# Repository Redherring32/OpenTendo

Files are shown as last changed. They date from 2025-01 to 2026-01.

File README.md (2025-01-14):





<br />

<p align="center">
  OSHW logo
</p>

# Open 'Tendo
An Open-Source HardWare (OSHW) recreation of the original 1985 Front-Loading NES motherboard.

## Note on RGB and HDMI

Neither RGB nor HDMI video output were or are a goal of the OpenTendo project, the goal was/is documentation and preservation, and the project was an exercise in reverse engineering. As such "improved" video outputs will not be added to OpenTendo.

NESRGB and Hi-Def NES can be installed as normal, but will not be incorporated into the OpenTendo PCB

## Repository Structure
### Branches
| Branch | Description |
| --- | --- |
| master | Latest revision of OpenTendo. This is a almost 1:1 of the OEM NES. |
| modded | Modded version of the latest revision (`master`). This houses any modification that is not in the OEM NES. |
| vX.X | Previous revisions of OpenTendo. (*ex.* v1.3) |
| vX.X_modded | Modded version of a previous revision. (*ex.* v1.3_modded) |

### File Structure
```
.
├── BOM              # Contains the bill of materials.
├── Board Files      # Contains all files necessary to open the project in KiCad.
|   └── Libraries    # Contains a library of all of the custom footprints used on the board.
├── Scans            # Contains the scans of the OEM NES board.
└── Schematics       # Contains schematics for the OEM frontloading NES board revisions,
                       some schematics represent more than one revision
```

The gerber files required to order PCBs can be found under [releases](https://github.com/Redherring32/OpenTendo/releases).

## Recommended PCB specs
* 2 layers

* 119mmx196mm

* 1.6mm thickness

* HASL or ENiG surface finish

* And any color you want!

> [!IMPORTANT]
> OpenTendo have some solder mask overlapping the edge connector to secure the pads and the thin traces. Some fabricators might see this as an error and might try to fix it.
>
> We recommend leaving a note saying that the solder mask overlap on the edge connector is intentional and NOT an error when ordering the PCB.

Board Front

The design is as true to the original board as possible, with subtle changes where needed to compensate for outdated/unsourcable parts,
as well as some improvements. (Expansion audio enabled, and other minor changes)

Since this project is open-source you may do as you like with it, whether that is to make boards for personal use, sell replacement NES boards, or to use the provided info for further custom PCB work/designs.

I am not in any way affiliated with Nintendo, I'm just doing this in my free time as a stepping stone into further Reverse Engineering work.

>[!NOTE]
> Please check the [BOM](./BOM#from-the-oem-nes) for the list of components needed from the OEM NES

## License

Licensed under
the TAPR Open Hardware License (www.tapr.org/OHL)

©Redherring32 2019-2024

## Credits
*=Lockster=* - Helping me tremendously along the way, keeping me from going insane, and cleaning up/helping with the final schematic. 

*Krzysiobal* - Putting together the NES-CPU-11 schematic that my schematic is largely referrenced against.

*[Muramasa](https://www.muramasaentertainment.com/)* - Ported to KiCad v8, PCB clean up, and fixing the EXP port footprint.

*[Kamoteshake](https://github.com/kamoteshake)* - Schematic clean up and fixing the EXP port footprint.

And to all of the awesome people in the NES scene, I wouldn't have been able to do this without the awesome work that some very clever people did before I got here.

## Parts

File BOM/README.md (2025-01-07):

# Bill of Materials
This is a list of components you need to build the OpenTendo NES. You will need some components from the original NES and have to order more modern components. Open [interactive_bom.html](./interactive_bom.html) on a browser to open an interactive BOM which shows you where the component is located on the board.

## From the OEM NES
| Reference | Qty | Part | Description |
| --- | :-: | ---- | --- |
| U5 | 1 | **NTSC:** RP2C02<br />**PAL:** RP2C07 | PPU |
| U6 | 1 | **NTSC:** RP2A03<br/>**PAL:** RP2A07 | CPU |
| U10 | 1 | 3193A | CIC |
| Q1 | 1 | A937 | Epitaxial planar PNP transistor |
| Q2, Q3| 2 | C2021 | 3 pin small signal bipolar transistor |
| DA1, DA3 | 2 | DAN601 | 7 pin small signal diode array |
| DA2, DA4 | 2 | UPA64H | 7 pin high speed switching diode array |
| P2 | 1 | Connector | 48 pin expansion port |
| P6 | 1 | Connector | 5 pin connector for the power/reset breakout board |

### Alternatives
| Reference | Qty | Part | Description |
| --- | :-: | ---- | --- |
| U5 | 1 | **NTSC:** UA6528 <sup>[1]</sup><br />**PAL:** UA6528P | PPU clone |
| U6 | 1 | **NTSC:** UA6527 <sup>[2]</sup><br />**PAL:** UA6527P | CPU clone |
| U10| 1 | [NullCIC](https://github.com/Redherring32/NullCIC)<sup>[3]</sup> | Small board to replace CIC |
| Q1 | 1 | [2SA937](https://octopart.com/2sa937-rohm-2179925)<sup>[4]</sup> | Epitaxial planar PNP transistor |
| Q2, Q3 | 2 | [2SC2021](https://octopart.com/2sc2021-rohm-2177186)<sup>[5]</sup> | 3 pin small signal bipolar transistor |
| DA1, DA3 | 2 | [DAN601](https://octopart.com/dan601-rohm-14372173)<sup>[6]</sup> | 7 pin small signal diode array |
| P2 | 2 | [PPPC241LFBN-RC](https://octopart.com/pppc241lfbn-rc-sullins-271073)<sup>[7]</sup> | 24 Pins Header Connector 0.100" (2.54mm) Through Hole |

> [!NOTE]
> <sup>[1]</sup> While it works as a direct drop-in replacement, it isn't known whether it is compatible with all NES games.
>
> <sup>[2]</sup> They are known to have different sounding audio due to swapped duty cycles, as such they aren't a 100% identical substitute, they otherwise work though.
>
> <sup>[3]</sup> [NullCIC](https://github.com/Redherring32/NullCIC) is optional. Use this if you want to remove the CIC but still have the reset functionality.
>
> <sup>[4][5][6]</sup> These components are discontinued and difficult to find. If you could find them, we recommend replacing the OEM. If not, the OEM components should still be fine.
>
> <sup>[7]</sup> If you don't want to use the OEM expansion port, you can replace it with a header pin connector or not put anything at all. OpenTendo should still work without the expansion port. 

## What to buy
We recommend using Octopart's [BOM tool](https://octopart.com/bom-tool/) and import the [BOM.csv](BOM.csv). This tool makes ordering from multiple Octopart's authorized distributors (Digikey, Mouser, etc.) easier. 

### Resistors
| Reference | Qty | Part | Description |
| --- | :-: | ---- | --- |
| RA1 | 1 | [4613X-101-103LF](https://octopart.com/4613x-101-103lf-bourns-1656444) | 10k Ohm ±2% 200mW Bussed 12 Resistor Array 13-SIP |
| RA2 | 1 | [4605X-101-682LF](https://octopart.com/4605x-101-682lf-bourns-1624703) | 6.8k Ohm Bussed 4 Resistor Array 5-SIP |
| R1 | 1 | [RNF14FTD1M00](https://octopart.com/rnf14ftd1m00-stackpole+electronics-19224733) | 1M OHM 1% 1/4W |
| R2, R12 | 2 | [CF18JT510R](https://octopart.com/cf18jt510r-stackpole+electronics-19205768) | 510 OHM 5% 1/8W |
| R3, R4 | 2 | [CF18JT100R](https://octopart.com/cf18jt100r-stackpole+electronics-19205641) | 100 OHM 5% 1/8W |
| R5 | 1 | [CF18JT220R](https://octopart.com/cf18jt220r-stackpole+electronics-19205701) | 220 OHM 5% 1/8W |
| R6 | 1 | [CF18JT47K0](https://octopart.com/cf18jt47k0-stackpole+electronics-19205759) | 47K OHM 5% 1/8W |
| R7, R9 | 2 | [CF18JT20K0](https://octopart.com/cf18jt20k0-stackpole+electronics-19205697) |	20K OHM 5% 1/8W |
| R8 | 1 | [CF18JT12K0](https://octopart.com/cf18jt12k0-stackpole+electronics-19205652) |	12K OHM 5% 1/8W |
| R10 | 1 | [CF18JT220K](https://octopart.com/cf18jt220k-stackpole+electronics-19205700) | 220K OHM 5% 1/8W |
| R11 | 1 | [CF18JT1K20](https://octopart.com/cf18jt1k20-stackpole+electronics-19205676) | 1.2K OHM 5% 1/8W |
| R13 | 1 | [CFR-25JB-52-150K](https://octopart.com/cfr-25jb-52-150k-yageo-22569037) | 150K OHM 5% 1/4W |
| R17 | 1 | [CF14JT2K20](https://octopart.com/cf14jt2k20-stackpole+electronics-19205454) | 2.2K OHM 5% 1/4W |
| R18, R19 | 2 | [CF18JT1K00](https://octopart.com/cf18jt1k00-stackpole+electronics-19205674) | 1K OHM 5% 1/8W |

### Capacitors
| Reference | Qty | Part | Description |
| --- | :-: | ---- | --- |
| BC1, BC2 | 2 | [K153K10X7RF5UH5](https://octopart.com/k153k10x7rf5uh5-vishay-44033224) | 0.015 µF 50V Ceramic Capacitor |
| TC1 | 1 | [GKG30015](https://octopart.com/gkg30015-panasonic-120079986)<sup>[1]</sup> | 6.5-30 pF Capacitor Trimmer |
| C1 | 1 | [ECE-A0JKA101I](https://octopart.com/ece-a0jka101i-panasonic-15327038) | 100 µF 6.3 V Electrolytic Capacitor |
| C2, C3, C4, C10,<br />C11, C12, C13,<br />C14, C15, C16,<br />C17, C18, C19,<br />C22, C24, C26,<br />C32, C38, C39,<br />C40 | 20 | [K103K10X7RF5UH5](https://octopart.com/k103k10x7rf5uh5-vishay-44280222) | 10000 pF 50V Ceramic Capacitor |
| C5, C27, C28, C29,<br />C30, C31, C33,<br />C34, C35, C36,<br />C37 | 11 | [K331K15X7RF53L2](https://octopart.com/k331k15x7rf53l2-vishay-42623274) | 330 pF 50V Ceramic Capacitor |
| C8, C46 | 2 | [K104K15X7RF5UH5](https://octopart.com/k104k15x7rf5uh5-vishay-40993312) | 0.1 µF 50V Ceramic Capacitor |
| C9 | 1 | [ECA-1HHG2R2I](https://octopart.com/eca-1hhg2r2i-panasonic-12553061) | 2.2 µF 50 V Electrolytic Capacitor |
| C20, C21, C44 | 3 | [K221K15X7RF5TL2](https://octopart.com/k221k15x7rf5tl2-vishay-39474895) | 220 pF 50V Ceramic Capacitor 2.5mm |
| C23 | 1 | [UVR2A010MDD1TD](https://octopart.com/uvr2a010mdd1td-nichicon-10319218) | 1 µF 100 V Electrolytic Capacitor |
| C41 | 1 | [FG18C0G1H180JNT00](https://octopart.com/fg18c0g1h180jnt00-tdk-75262881) | 18 pF 50V Ceramic Capacitor |
| C42 | 1 | [K150J15C0GF5TL2](https://octopart.com/k150j15c0gf5tl2-vishay-39474466) | 15 pF 50V Ceramic Capacitor |
| C43, C45 | 2 | [K560J15C0GF5TL2](https://octopart.com/k560j15c0gf5tl2-vishay-39474510)<sup>[2]</sup> | 56 pF 50V Ceramic Capacitor |

> [!NOTE]
> <sup>[1]</sup> You might have to trim the capacitor to get a stable clock (21.47727MHz for NTSC and 26.601712MHz for PAL). If you don't have a way to probe the clock, We recommend just using the X1 and TC1 from the OEM NES.
>
> <sup>[2]</sup> The OEM is using 51pF for C43 and C45. It's been difficult to find a 51pF Ceramic Capacitor. Using a 56pF is fine and have been tested.

### ICs
| Reference | Qty | Part | Description |
| --- | :-: | ---- | --- |
| U1, U4 | 2 | [6116SA15SOG](https://octopart.com/6116sa15sog-renesas-106910578)<sup>[1]</sups> | SRAM Chip Async Single 5V 16K-Bit 2K x 8 15ns 24-Pin SOIC |
| U2 | 1 | [SN74HC373N](https://octopart.com/sn74hc373n-texas+instruments-471147) | D-Type Transparent Latch 1 Channel 8:8 IC Tri-State 20-PDIP |
| U3 | 1 | [SN74HC139N](https://octopart.com/sn74hc139n-texas+instruments-17212) | Decoder/Demultiplexer 1 x 2:4 16-PDIP |
| U7, U8 | 2 | [SN74HC368N](https://octopart.com/sn74hc368n-texas+instruments-51845) | Buffer, Inverting 2 Element 2, 4 (Hex) Bit per Element 3-State Output 16-PDIP |
| U9 | 1 | [SN74HCU04N](https://octopart.com/sn74hcu04n-texas+instruments-465549) | Inverter IC 6 Channel 14-PDIP |

#### Alternatives
| Reference | Qty | Part | Description |
| --- | :-: | ---- | --- |
| U1, U4 | 2 | [6116SA15TPG](https://octopart.com/6116sa15tpg-renesas-106910580) | SRAM - Asynchronous Memory IC 16Kb (2K x 8) Parallel 15ns 24-PDIP |

> [!NOTE]
> <sup>[1]</sup> This component is an SOIC. You would need an SOIC to DIP adaptor (`PA0009`), listed in [Others](#others), to be able to use this component. If you're not comfortable working with SOIC, We recommend looking for the alternative `6116SA15TPG` or use the SRAM from the OEM NES.

### Connectors
| Reference | Qty | Part | Description |
| --- | :-: | ---- | --- |
| U5, U6 | 2 | [ED40DT](https://octopart.com/ed40dt-on+shore+technology-5349672) | 40 (2 x 20) Pos DIP, 0.6" (15.24mm) Row Spacing Socket Tin Through Hole |
| P4, P5 | 2 | [S7B-PH-K-S(LF)(SN)](https://octopart.com/s7b-ph-k-s%28lf%29%28sn%29-jst-248888) | JST PH 2mm 7 Pins Male |

### Others
| Reference | Qty | Part | Description |
| --- | :-: | ---- | --- |
| X1 | 1 | **NTSC**: [ECS-214-S-4X](https://octopart.com/ecs-214-s-4x-ecs+international-88334749)<br />**PAL:** N/A<sup>[1]</sup>  | **NTSC:** 21.47727MHz Crystal<br />**PAL:** 26.601712MHz Crystal |
| X2 | 1 | [CSTLS4M00G56-B0](https://octopart.com/cstls4m00g56-b0-murata-10326657) | 4 MHz Ceramic Resonator Built in Capacitor 47 pF |
| D1, D2 | 2 | [1N5231BTR](https://octopart.com/1n5231btr-onsemi-12156453) | Zener Diode 5.1 V 500 mW Through Hole |
| FC1 | 1 | [B78108S1393K](https://octopart.com/b78108s1393k-epcos-39569030) | 39 µH Unshielded Drum Core, Wirewound Inductor 470 mA 1.02Ohm Max Axial |
| FC2 | 1 | [28L0138-10R-10](https://octopart.com/28l0138-10r-10-laird-19252911) | 75 Ohms @ 100 MHz 1 Ferrite Bead Axial 5A 10mOhm |
| U1, U4 | 2 | [PA0009](https://octopart.com/pa0009-chip+quik-51024752)<sup>[2]</sup> | SOIC-24 to DIP-24 SMT Adapte |

> [!NOTE]
> <sup>[1]</sup> We couldn't find a good part number for a crystal for PAL system. We recommend searching the internet to find a 26.601712MHz crystal for PAL.
>
> <sup>[2]</sup> You only need this adaptor if you're using the `6116SA15SOG` SRAM. When using this adaptor, you will need additional header connector (`PPPC241LFBN-RC`).

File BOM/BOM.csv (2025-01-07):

Query | Qty | Manufacturer | MPN | Octopart URL | Part Description | Description | Schematic Reference | Internal Part Number | Lifecycle | Lead Time | RoHS | Total Qty (@ Batch Size: 1) | SKU | SKU | SKU | SKU | SKU | Packaging | Packaging | Packaging | Packaging | Packaging | Unit Price (@ Batch Size: 1) | Unit Price (@ Batch Size: 1) | Unit Price (@ Batch Size: 1) | Unit Price (@ Batch Size: 1) | Unit Price (@ Batch Size: 1) | In Stock | In Stock | In Stock | In Stock | In Stock | MOQ | MOQ | MOQ | MOQ | MOQ | URL | URL | URL | URL | URL | Distributor [Lowest Price (Preferred Distributors)] | SKU [Lowest Price (Preferred Distributors)] | Packaging [Lowest Price (Preferred Distributors)] | Unit Price (@ Batch Size: 1) [Lowest Price (Preferred Distributors)] | Line Total [Lowest Price (Preferred Distributors)] | Batch Total [Lowest Price (Preferred Distributors)] | In Stock [Lowest Price (Preferred Distributors)] | MOQ [Lowest Price (Preferred Distributors)] | URL [Lowest Price (Preferred Distributors)] | Notes
 |  |  |  |  |  |  |  |  |  |  |  |  | Digi-Key | Mouser | Newark | Onlinecomponents.com | RS Components | Digi-Key | Mouser | Newark | Onlinecomponents.com | RS Components | Digi-Key | Mouser | Newark | Onlinecomponents.com | RS Components | Digi-Key | Mouser | Newark | Onlinecomponents.com | RS Components | Digi-Key | Mouser | Newark | Onlinecomponents.com | RS Components | Digi-Key | Mouser | Newark | Onlinecomponents.com | RS Components
CSTLS4M00G56-B0 | 1 | Murata | CSTLS4M00G56-B0 | https://octopart.com/cstls4m00g56-b0-murata-10326657 | Ceramic Resonator 4MHz ±0.5% (Tol) -0.4/0.2% (Stability) 47pF 30Ohm 3-Pin Thru-Hole Bulk |  | X2 |  | NRND (Last Updated: 2 weeks ago) | 15w | Compliant | 1 | 490-7036-ND | 81-CSTLS4M00G56-B0 | 70AC3726 |  |  | Bulk | Bulk |  |  |  | 0.21 | 0.21 | 0.209 |  |  | 4715 | 2001 | 324 |  |  | 1 | 1 | 1 |  |  | https://octopart.com/opatz8j6/a1 | https://octopart.com/opatz8j6/a1 | https://octopart.com/opatz8j6/a1 |  |  | Newark | 70AC3726 |  | 0.209 | 0.209 | 0.209 | 324 | 1 | https://octopart.com/opatz8j6/a1
ECS-214-S-4X | 1 | ECS International | ECS-214-S-4X | https://octopart.com/ecs-214-s-4x-ecs+international-88334749 |  |  | X1 |  |  |  | Compliant | 1 |  | 520-HCU2147-SX |  |  |  |  | Bulk |  |  |  |  | 0.69 |  |  |  |  | 558 |  |  |  |  | 1 |  |  |  |  | https://octopart.com/opatz8j6/a1 |  |  |  | Mouser | 520-HCU2147-SX | Bulk | 0.69 | 0.69 | 0.69 | 558 | 1 | https://octopart.com/opatz8j6/a1
SN74HCU04N | 1 | Texas Instruments | SN74HCU04N | https://octopart.com/sn74hcu04n-texas+instruments-465549 | Gate / Inverter Logic IC Leaded Process; function (IC): Hex Inverter; Base Number: 7404 |  | U9 |  | Production (Last Updated: 1 week ago) | 1w | Compliant | 1 | 296-9820-5-ND | 595-SN74HCU04N |  |  |  | Tube | Tube |  |  |  | 0.63 | 0.59 |  |  |  | 2448 | 1088 |  |  |  | 1 | 1 |  |  |  | https://octopart.com/opatz8j6/a1 | https://octopart.com/opatz8j6/a1 |  |  |  | Mouser | 595-SN74HCU04N | Tube | 0.59 | 0.59 | 0.59 | 1088 | 1 | https://octopart.com/opatz8j6/a1
SN74HC368N | 1 | Texas Instruments | SN74HC368N | https://octopart.com/sn74hc368n-texas+instruments-51845 | Buffer/Line Driver 6-CH Inverting 3-ST CMOS 16-Pin PDIP Tube |  | U8 |  | Production (Last Updated: 1 week ago) | 1w | Compliant | 1 | 296-8308-5-ND | 595-SN74HC368N |  |  |  | Tube | Tube |  |  |  | 0.65 | 0.57 |  |  |  | 4259 | 951 |  |  |  | 1 | 1 |  |  |  | https://octopart.com/opatz8j6/a1 | https://octopart.com/opatz8j6/a1 |  |  |  | Mouser | 595-SN74HC368N | Tube | 0.57 | 0.57 | 0.57 | 951 | 1 | https://octopart.com/opatz8j6/a1
SN74HC368N | 1 | Texas Instruments | SN74HC368N | https://octopart.com/sn74hc368n-texas+instruments-51845 | Buffer/Line Driver 6-CH Inverting 3-ST CMOS 16-Pin PDIP Tube |  | U7 |  | Production (Last Updated: 1 week ago) | 1w | Compliant | 1 | 296-8308-5-ND | 595-SN74HC368N |  |  |  | Tube | Tube |  |  |  | 0.65 | 0.57 |  |  |  | 4259 | 951 |  |  |  | 1 | 1 |  |  |  | https://octopart.com/opatz8j6/a1 | https://octopart.com/opatz8j6/a1 |  |  |  | Mouser | 595-SN74HC368N | Tube | 0.57 | 0.57 | 0.57 | 951 | 1 | https://octopart.com/opatz8j6/a1
ED40DT | 2 | On Shore Technology | ED40DT | https://octopart.com/ed40dt-on+shore+technology-5349672 | Conn DIP Socket SKT 40 POS Solder ST Thru-Hole |  | U5, U6 |  |  | 8w | Compliant | 2 | ED3048-5-ND |  |  |  |  | Tube |  |  |  |  | 0.59 |  |  |  |  | 1677 |  |  |  |  | 1 |  |  |  |  | https://octopart.com/opatz8j6/a1 |  |  |  |  | DigiKey | ED3048-5-ND | Tube | 0.59 | 1.18 | 1.18 | 1677 | 1 | https://octopart.com/opatz8j6/a1
SN74HC139N | 1 | Texas Instruments | SN74HC139N | https://octopart.com/sn74hc139n-texas+instruments-17212 | Decoder/Demultiplexer; Dual 2 to 4 Line Decoder-Demultiplexer; 0 to 5 V; PDIP |  | U3 |  | Production (Last Updated: 1 week ago) | 1w | Compliant | 1 | 296-8230-5-ND | 595-SN74HC139N | 33AH4851 |  |  | Tube | Tube |  |  |  | 1.31 | 1.28 | 0.147 |  |  | 102 | 1545 | 19 |  |  | 1 | 1 | 1 |  |  | https://octopart.com/opatz8j6/a1 | https://octopart.com/opatz8j6/a1 | https://octopart.com/opatz8j6/a1 |  |  | Newark | 33AH4851 |  | 0.147 | 0.147 | 0.147 | 19 | 1 | https://octopart.com/opatz8j6/a1
SN74HC373N | 1 | Texas Instruments | SN74HC373N | https://octopart.com/sn74hc373n-texas+instruments-471147 | Latch; Octal Transparent D-Type Latch; 0 to 5 V; 500 ns (Max.) @ 4.5 V; PDIP-N |  | U2 |  | Production (Last Updated: 1 week ago) | 6w | Compliant | 1 | 296-1591-5-ND | 595-SN74HC373N | 29AH1488 |  |  | Tube | Tube |  |  |  | 0.82 | 0.78 | 0.822 |  |  | 0 | 130 | 50 |  |  | 1 | 1 | 1 |  |  | https://octopart.com/opatz8j6/a1 | https://octopart.com/opatz8j6/a1 | https://octopart.com/opatz8j6/a1 |  |  | Mouser | 595-SN74HC373N | Tube | 0.78 | 0.78 | 0.78 | 130 | 1 | https://octopart.com/opatz8j6/a1
6116SA15SOG | 2 | Renesas | 6116SA15SOG | https://octopart.com/6116sa15sog-renesas-106910578 | SRAM Chip Async Single 5V 16K-Bit 2K x 8 15ns 24-Pin SOIC Tube/Tray |  | U1, U4 |  | Production (Last Updated: 1 week ago) | 1w | Compliant | 2 | 6116SA15SOG-ND | 972-6116SA15SOG |  |  |  | Tube | Tube |  |  |  | 6.44 | 6.19 |  |  |  | 282 | 202 |  |  |  | 1 | 1 |  |  |  | https://octopart.com/opatz8j6/a1 | https://octopart.com/opatz8j6/a1 |  |  |  | Mouser | 972-6116SA15SOG | Tube | 6.19 | 12.38 | 12.38 | 202 | 1 | https://octopart.com/opatz8j6/a1 | Alternate: Renesas 6116SA15TPG
PA0009 | 2 | Chip Quik | PA0009 | https://octopart.com/pa0009-chip+quik-51024752 | SOIC-24 to DIP-24 SMT Adapter |  | U1, U4 |  |  | 4w | Compliant | 2 | PA0009-ND | 910-PA0009 |  |  |  | Bulk |  |  |  |  | 5.29 | 5.29 |  |  |  | 222 | 100 |  |  |  | 1 | 1 |  |  |  | https://octopart.com/opatz8j6/a1 | https://octopart.com/opatz8j6/a1 |  |  |  | DigiKey | PA0009-ND | Bulk | 5.29 | 10.58 | 10.58 | 222 | 1 | https://octopart.com/opatz8j6/a1
4613X-101-103LF | 1 | Bourns | 4613X-101-103LF | https://octopart.com/4613x-101-103lf-bourns-1656444 | Res Thick Film NET 10K Ohm 2% 1.63W ±100ppm/°C BUS Conformal 13-Pin SIP Pin Thru-Hole Bulk |  | RA1 |  |  | 15w | Compliant | 1 | 4613X-101-103LF-ND | 652-4613X-1LF-10K | 67AC8758 | 4613X-101-103LF |  | Bulk | Bulk |  | Bulk |  | 0.75 | 0.59 | 0.643 |  |  | 887 | 704 | 541 | 0 |  | 1 | 1 | 1 | 500 |  | https://octopart.com/opatz8j6/a1 | https://octopart.com/opatz8j6/a1 | https://octopart.com/opatz8j6/a1 | https://octopart.com/opatz8j6/a1 |  | Mouser | 652-4613X-1LF-10K | Bulk | 0.59 | 0.59 | 0.59 | 704 | 1 | https://octopart.com/opatz8j6/a1
4605X-101-682LF | 1 | Bourns | 4605X-101-682LF | https://octopart.com/4605x-101-682lf-bourns-1624703 | Res Thick Film NET 6.8K Ohm 2% 63/100W ±100ppm/°C BUS Conformal 5-Pin SIP Pin Thru-Hole Bulk |  | RA2 |  |  | 15w | Compliant | 1 | 4605X-101-682LF-ND | 652-4605X-1LF-6.8K | 67AC8736 | 4605X-101-682LF |  | Bulk | Bulk |  | Bulk |  | 0.37 | 0.35 | 0.355 |  |  | 1524 | 1734 | 1988 | 0 |  | 1 | 1 | 1 | 1000 |  | https://octopart.com/opatz8j6/a1 | https://octopart.com/opatz8j6/a1 | https://octopart.com/opatz8j6/a1 | https://octopart.com/opatz8j6/a1 |  | Mouser | 652-4605X-1LF-6.8K | Bulk | 0.35 | 0.35 | 0.35 | 1734 | 1 | https://octopart.com/opatz8j6/a1
CF18JT1K00 | 2 | Stackpole Electronics | CF18JT1K00 | https://octopart.com/cf18jt1k00-stackpole+electronics-19205674 | Res Carbon Film 1K Ohm 5% 0.125W(1/8W) -400ppm/ to 0ppm/ Conformal Coated AXL T/R |  | R18, R19 |  |  | 17w | Compliant | 2 | CF18JT1K00CT-ND | 708-CF18JT1K00 |  | CF18JT1K00 |  | Cut Tape | Tape & Reel |  | Bulk |  | 0.1 | 0.1 |  |  |  | 138926 | 31947 |  | 15000 |  | 1 | 1 |  | 5000 |  | https://octopart.com/opatz8j6/a1 | https://octopart.com/opatz8j6/a1 |  | https://octopart.com/opatz8j6/a1 |  | DigiKey | CF18JT1K00CT-ND | Cut Tape | 0.1 | 0.2 | 0.2 | 138926 | 1 | https://octopart.com/opatz8j6/a1
CF14JT2K20 | 1 | Stackpole Electronics | CF14JT2K20 | https://octopart.com/cf14jt2k20-stackpole+electronics-19205454 | CF FIXED RESISTOR Axial Through Hole Resistor ±5% 0/ -400ppm/C 2.2kOhm 0.25W 1/4W |  | R17 |  |  | 17w | Compliant | 1 | CF14JT2K20CT-ND | 708-CF14JT2K20 | 31AC8468 | CF14JT2K20 |  | Cut Tape | Tape & Reel | Tape & Reel | Bulk |  | 0.1 | 0.1 |  |  |  | 157243 | 82839 | 10000 | 75000 |  | 1 | 1 | 5000 | 5000 |  | https://octopart.com/opatz8j6/a1 | https://octopart.com/opatz8j6/a1 | https://octopart.com/opatz8j6/a1 | https://octopart.com/opatz8j6/a1 |  | DigiKey | CF14JT2K20CT-ND | Cut Tape | 0.1 | 0.1 | 0.1 | 157243 | 1 | https://octopart.com/opatz8j6/a1
CFR-25JB-52-150K | 1 | Yageo | CFR-25JB-52-150K | https://octopart.com/cfr-25jb-52-150k-yageo-22569037 | General Type Carbon Film Resistor 150kOhm 1/4W 5% Axial Bulk |  | R13 |  |  | 16w | Compliant | 1 | 150KQBK-ND | 603-CFR-25JB-52-150K | 49AK4906 |  |  | Bulk | Bulk |  |  |  | 0.1 | 0.1 | 0.01 |  |  | 6389 | 1788 | 8393 |  |  | 1 | 1 | 1 |  |  | https://octopart.com/opatz8j6/a1 | https://octopart.com/opatz8j6/a1 | https://octopart.com/opatz8j6/a1 |  |  | Newark | 49AK4906 |  | 0.01 | 0.01 | 0.01 | 8393 | 1 | https://octopart.com/opatz8j6/a1
CF18JT1K20 | 1 | Stackpole Electronics | CF18JT1K20 | https://octopart.com/cf18jt1k20-stackpole+electronics-19205676 | CF FIXED RESISTOR Axial Through Hole Resistor ±5% 0/ -400ppm/C 1.2kOhm 0.125W 1/8W |  | R11 |  |  | 17w | Compliant | 1 | CF18JT1K20CT-ND | 708-CF18JT1K20 |  | CF18JT1K20 |  | Cut Tape | Tape & Reel |  | Bulk |  | 0.1 | 0.1 |  |  |  | 16462 | 9887 |  | 0 |  | 1 | 1 |  | 5000 |  | https://octopart.com/opatz8j6/a1 | https://octopart.com/opatz8j6/a1 |  | https://octopart.com/opatz8j6/a1 |  | DigiKey | CF18JT1K20CT-ND | Cut Tape | 0.1 | 0.1 | 0.1 | 16462 | 1 | https://octopart.com/opatz8j6/a1
CF18JT220K | 1 | Stackpole Electronics | CF18JT220K | https://octopart.com/cf18jt220k-stackpole+electronics-19205700 | CF FIXED RESISTOR Axial Through Hole Resistor ±5% 0/ -850ppm/C 220kOhm 0.125W 1/8W |  | R10 |  |  | 17w | Compliant | 1 | CF18JT220KCT-ND | 708-CF18JT220K |  | CF18JT220K |  | Cut Tape | Tape & Reel |  | Bulk |  | 0.1 | 0.1 |  |  |  | 30939 | 9700 |  | 0 |  | 1 | 1 |  | 5000 |  | https://octopart.com/opatz8j6/a1 | https://octopart.com/opatz8j6/a1 |  | https://octopart.com/opatz8j6/a1 |  | DigiKey | CF18JT220KCT-ND | Cut Tape | 0.1 | 0.1 | 0.1 | 30939 | 1 | https://octopart.com/opatz8j6/a1
CF18JT12K0 | 1 | Stackpole Electronics | CF18JT12K0 | https://octopart.com/cf18jt12k0-stackpole+electronics-19205652 | CF FIXED RESISTOR Axial Through Hole Resistor ±5% 0/ -500ppm/C 12kOhm 0.125W 1/8W |  | R8 |  |  | 17w | Compliant | 1 | CF18JT12K0CT-ND | 708-CF18JT12K0 |  | CF18JT12K0 |  | Cut Tape | Tape & Reel |  | Bulk |  | 0.1 | 0.1 |  |  |  | 16632 | 9736 |  | 0 |  | 1 | 1 |  | 5000 |  | https://octopart.com/opatz8j6/a1 | https://octopart.com/opatz8j6/a1 |  | https://octopart.com/opatz8j6/a1 |  | DigiKey | CF18JT12K0CT-ND | Cut Tape | 0.1 | 0.1 | 0.1 | 16632 | 1 | https://octopart.com/opatz8j6/a1
CF18JT20K0 | 2 | Stackpole Electronics | CF18JT20K0 | https://octopart.com/cf18jt20k0-stackpole+electronics-19205697 | CF FIXED RESISTOR Axial Through Hole Resistor ±5% 0/ -500ppm/C 20kOhm 0.125W 1/8W |  | R7, R9 |  |  | 17w | Compliant | 2 | CF18JT20K0CT-ND | 708-CF18JT20K0 |  | CF18JT20K0 |  | Cut Tape | Tape & Reel |  | Bulk |  | 0.1 | 0.1 |  |  |  | 66822 | 22435 |  | 0 |  | 1 | 1 |  | 5000 |  | https://octopart.com/opatz8j6/a1 | https://octopart.com/opatz8j6/a1 |  | https://octopart.com/opatz8j6/a1 |  | DigiKey | CF18JT20K0CT-ND | Cut Tape | 0.1 | 0.2 | 0.2 | 66822 | 1 | https://octopart.com/opatz8j6/a1
CF18JT47K0 | 1 | Stackpole Electronics | CF18JT47K0 | https://octopart.com/cf18jt47k0-stackpole+electronics-19205759 | Res Carbon Film 47K Ohm 5% 0.125W(1/8W) -500ppm/ to 0ppm/ Conformal Coated AXL T/R |  | R6 |  |  | 17w | Compliant | 1 | CF18JT47K0CT-ND | 708-CF18JT47K0 |  | CF18JT47K0 |  | Cut Tape | Tape & Reel |  | Bulk |  | 0.1 | 0.1 |  |  |  | 205528 | 10457 |  | 35000 |  | 1 | 1 |  | 5000 |  | https://octopart.com/opatz8j6/a1 | https://octopart.com/opatz8j6/a1 |  | https://octopart.com/opatz8j6/a1 |  | DigiKey | CF18JT47K0CT-ND | Cut Tape | 0.1 | 0.1 | 0.1 | 205528 | 1 | https://octopart.com/opatz8j6/a1
CF18JT220R | 1 | Stackpole Electronics | CF18JT220R | https://octopart.com/cf18jt220r-stackpole+electronics-19205701 | CF FIXED RESISTOR Axial Through Hole Resistor ±5% 0/ -400ppm/C 220Ohm 0.125W 1/8W |  | R5 |  |  | 17w | Compliant | 1 | CF18JT220RCT-ND | 708-CF18JT220R |  | CF18JT220R |  | Cut Tape | Tape & Reel |  | Bulk |  | 0.1 | 0.1 |  |  |  | 44352 | 7668 |  | 0 |  | 1 | 1 |  | 5000 |  | https://octopart.com/opatz8j6/a1 | https://octopart.com/opatz8j6/a1 |  | https://octopart.com/opatz8j6/a1 |  | DigiKey | CF18JT220RCT-ND | Cut Tape | 0.1 | 0.1 | 0.1 | 44352 | 1 | https://octopart.com/opatz8j6/a1
CF18JT100R | 2 | Stackpole Electronics | CF18JT100R | https://octopart.com/cf18jt100r-stackpole+electronics-19205641 | Res Carbon Film 100 Ohm 5% 0.125W(1/8W) -400ppm/ to 0ppm/ Conformal Coated AXL T/R |  | R3, R4 |  |  | 17w | Compliant | 2 | CF18JT100RCT-ND | 708-CF18JT100R |  | CF18JT100R |  | Cut Tape | Tape & Reel |  | Bulk |  | 0.1 | 0.1 |  |  |  | 80062 | 446 |  | 0 |  | 1 | 1 |  | 5000 |  | https://octopart.com/opatz8j6/a1 | https://octopart.com/opatz8j6/a1 |  | https://octopart.com/opatz8j6/a1 |  | DigiKey | CF18JT100RCT-ND | Cut Tape | 0.1 | 0.2 | 0.2 | 80062 | 1 | https://octopart.com/opatz8j6/a1
CF18JT510R | 2 | Stackpole Electronics | CF18JT510R | https://octopart.com/cf18jt510r-stackpole+electronics-19205768 | CF FIXED RESISTOR Axial Through Hole Resistor ±5% 0/ -400ppm/C 510Ohm 0.125W 1/8W |  | R2, R12 |  |  | 17w | Compliant | 2 | CF18JT510RCT-ND | 708-CF18JT510R |  | CF18JT510R |  | Cut Tape | Tape & Reel |  | Bulk |  | 0.1 | 0.1 |  |  |  | 37165 | 9636 |  | 0 |  | 1 | 1 |  | 5000 |  | https://octopart.com/opatz8j6/a1 | https://octopart.com/opatz8j6/a1 |  | https://octopart.com/opatz8j6/a1 |  | DigiKey | CF18JT510RCT-ND | Cut Tape | 0.1 | 0.2 | 0.2 | 37165 | 1 | https://octopart.com/opatz8j6/a1
RNF14FTD1M00 | 1 | Stackpole Electronics | RNF14FTD1M00 | https://octopart.com/rnf14ftd1m00-stackpole+electronics-19224733 | RNF FIXED RESISTOR Axial Through Hole Resistor ±1% ±100ppm/C 1MOhm 0.25W 1/4W |  | R1 |  |  | 17w | Compliant | 1 | RNF14FTD1M00CT-ND | 708-RNF14FTD1M00 |  | RNF14FTD1M00 |  | Cut Tape | Tape & Reel |  | Bulk |  | 0.1 | 0.1 |  |  |  | 45933 | 43168 |  | 10000 |  | 1 | 1 |  | 5000 |  | https://octopart.com/opatz8j6/a1 | https://octopart.com/opatz8j6/a1 |  | https://octopart.com/opatz8j6/a1 |  | DigiKey | RNF14FTD1M00CT-ND | Cut Tape | 0.1 | 0.1 | 0.1 | 45933 | 1 | https://octopart.com/opatz8j6/a1
2SC2021 | 2 | ROHM | 2SC2021 | https://octopart.com/2sc2021-rohm-2177186 |  |  | Q2, Q3 |  |  |  | Non-Compliant | 2
2SA937 | 1 | ROHM | 2SA937 | https://octopart.com/2sa937-rohm-2179925 |  |  | Q1 |  |  |  | Non-Compliant | 1
S7B-PH-K-S(LF)(SN) | 2 | JST | S7B-PH-K-S (LF)(SN) | https://octopart.com/s7b-ph-k-s+%28lf%29%28sn%29-jst-5373080 | Header for PCB; pitch 2.00mm; 7-contacts; THT; male; side entry; 100V/2A |  | P4, P5 |  |  |  | Compliant | 2 |  |  | 38K8083 |  |  |  |  |  |  |  |  |  |  |  |  |  |  | 78 |  |  |  |  | 10 |  |  |  |  | https://octopart.com/opatz8j6/a1 |  |  | Newark | 38K8083 |  |  |  |  | 78 | 10 | https://octopart.com/opatz8j6/a1
PPPC241LFBN-RC | 2 | Sullins | PPPC241LFBN-RC | https://octopart.com/pppc241lfbn-rc-sullins-271073 | 24 Position Header Connector 0.100 (2.54mm) Through Hole Gold |  | P2 |  |  | 11w | Compliant | 2 | S7057-ND |  |  |  |  | Tray |  |  |  |  | 1.77 |  |  |  |  | 2637 |  |  |  |  | 1 |  |  |  |  | https://octopart.com/opatz8j6/a1 |  |  |  |  | DigiKey | S7057-ND | Tray | 1.77 | 3.54 | 3.54 | 2637 | 1 | https://octopart.com/opatz8j6/a1
28L0138-10R-10 | 1 | Laird | 28L0138-10R-10 | https://octopart.com/28l0138-10r-10-laird-19252911 | Emi Ferrite Bead With Axial Wire, 5A, 75 Ohms @100MHZ, Dcr Max 0.01 Ohm |  | FC2 |  | Production (Last Updated: 3 years ago) | 14w | Compliant | 1 | 240-2438-1-ND | 875-28L0138-10R-10 | 67W0706 |  |  | Cut Tape | Tape & Reel | Cut Tape |  |  | 0.24 | 0.24 |  |  |  | 41197 | 27634 | 17994 |  |  | 1 | 1 | 10 |  |  | https://octopart.com/opatz8j6/a1 | https://octopart.com/opatz8j6/a1 | https://octopart.com/opatz8j6/a1 |  |  | DigiKey | 240-2438-1-ND | Cut Tape | 0.24 | 0.24 | 0.24 | 41197 | 1 | https://octopart.com/opatz8j6/a1
B78108S1393K | 1 | EPCOS | B78108S1393K | https://octopart.com/b78108s1393k-epcos-39569030 | Fixed Inductor RF Choke 39uH 10% Wirewound 470mA 1020 mOhm Unshielded Axial |  | FC1 |  | Production (Last Updated: 2 years ago) | 9w | Compliant | 1 | 495-5565-1-ND | 871-B78108S1393K |  |  |  | Cut Tape | Tape & Reel |  |  |  | 0.3 | 0.32 |  |  |  | 9658 | 6091 |  |  |  | 1 | 1 |  |  |  | https://octopart.com/opatz8j6/a1 | https://octopart.com/opatz8j6/a1 |  |  |  | DigiKey | 495-5565-1-ND | Cut Tape | 0.3 | 0.3 | 0.3 | 9658 | 1 | https://octopart.com/opatz8j6/a1
DAN601 | 2 | ROHM | DAN601 | https://octopart.com/dan601-rohm-14372173 |  | small signal diode array | DA1, DA3 |  |  |  | Non-Compliant | 2
1N5231BTR | 2 | onsemi | 1N5231BTR | https://octopart.com/1n5231btr-onsemi-12156453 | 1N5231 Series 500 mW 5.1 V 200 mA Through Hole Zener Diode - DO-35 |  | D1, D2 |  | Production (Last Updated: 3 years ago) | 22w | Compliant | 2 | 1N5231BFSCT-ND | 512-1N5231BTR | 05R0368 | 1N5231BTR |  | Cut Tape | Tape & Reel | Cut Tape | Bulk |  | 0.1 | 0.14 | 0.158 |  |  | 38386 | 63101 | 20617 | 120000 |  | 1 | 1 | 1 | 5000 |  | https://octopart.com/opatz8j6/a1 | https://octopart.com/opatz8j6/a1 | https://octopart.com/opatz8j6/a1 | https://octopart.com/opatz8j6/a1 |  | DigiKey | 1N5231BFSCT-ND | Cut Tape | 0.1 | 0.2 | 0.2 | 38386 | 1 | https://octopart.com/opatz8j6/a1
K560J15C0GF5TL2 | 2 | Vishay | K560J15C0GF5TL2 | https://octopart.com/k560j15c0gf5tl2-vishay-39474510 | Capacitor Ceramic 56PF 50V, C0G/NP0, 5%, |  | C43, C45 |  |  | 17w | Compliant | 2 | BC1010CT-ND | 594-K560J15C0GF5TL2 | 73AJ7908 |  |  | Cut Tape | Tape & Reel |  |  |  | 0.24 | 0.24 |  |  |  | 28892 | 14404 | 17730 |  |  | 1 | 1 | 10 |  |  | https://octopart.com/opatz8j6/a1 | https://octopart.com/opatz8j6/a1 | https://octopart.com/opatz8j6/a1 |  |  | Mouser | 594-K560J15C0GF5TL2 | Tape & Reel | 0.24 | 0.48 | 0.48 | 14404 | 1 | https://octopart.com/opatz8j6/a1
K150J15C0GF5TL2 | 1 | Vishay | K150J15C0GF5TL2 | https://octopart.com/k150j15c0gf5tl2-vishay-39474466 | K Series 15 pF 50 V ±5 % Tolerance C0G Radial Multilayer Ceramic Capacitor |  | C42 |  |  | 17w | Compliant | 1 | BC1003CT-ND | 594-K150J15C0GF5TL2 | 95C0990 |  |  | Cut Tape | Tape & Reel | Cut Tape |  |  | 0.25 | 0.25 | 0.048 |  |  | 37400 | 23292 | 5373 |  |  | 1 | 1 | 1 |  |  | https://octopart.com/opatz8j6/a1 | https://octopart.com/opatz8j6/a1 | https://octopart.com/opatz8j6/a1 |  |  | Newark | 95C0990 | Cut Tape | 0.048 | 0.048 | 0.048 | 5373 | 1 | https://octopart.com/opatz8j6/a1
C315C180J5G5TA | 1 | KEMET | C315C180J5G5TA | https://octopart.com/c315c180j5g5ta-kemet-1839992 | Cap Ceramic 18pF 50V C0G 5% Radial 2.54mm 125 C Bulk |  | C41 |  |  | 13w | Compliant | 1 | 399-C315C180J5G5TA-ND | 80-C315C180J5G5TA |  |  |  | Bulk | Bulk |  |  |  | 0.43 | 0.28 |  |  |  | 480 | 2574 |  |  |  | 1 | 1 |  |  |  | https://octopart.com/opatz8j6/a1 | https://octopart.com/opatz8j6/a1 |  |  |  | Mouser | 80-C315C180J5G5TA | Bulk | 0.28 | 0.28 | 0.28 | 2574 | 1 | https://octopart.com/opatz8j6/a1 | Alternate: TDK FG18C0G1H180JNT00
UVR2A010MDD1TD | 1 | Nichicon | UVR2A010MDD1TD | https://octopart.com/uvr2a010mdd1td-nichicon-10319218 | Radial Can ALUMINUM ELECTROLYTIC CAPACITOR UVR 100V 1muF ±20% 0.197Dia 5.00mm |  | C23 |  |  | 21w | Compliant | 1 | 493-12811-1-ND | 647-UVR2A010MDD1TD |  |  |  | Cut Tape | Ammo Pack |  |  |  | 0.27 | 0.26 |  |  |  | 2203 | 3474 |  |  |  | 1 | 1 |  |  |  | https://octopart.com/opatz8j6/a1 | https://octopart.com/opatz8j6/a1 |  |  |  | Mouser | 647-UVR2A010MDD1TD | Ammo Pack | 0.26 | 0.26 | 0.26 | 3474 | 1 | https://octopart.com/opatz8j6/a1
K221K15X7RF5TL2 | 3 | Vishay | K221K15X7RF5TL2 | https://octopart.com/k221k15x7rf5tl2-vishay-39474895 | Cap Ceramic 220pF 50V X7R 10% Radial 2.5mm 125C T/R |  | C20, C21, C44 |  |  | 17w | Compliant | 3 | BC1068CT-ND | 594-K221K15X7RF5TL2 | 57AC2378 |  |  | Cut Tape | Tape & Reel |  |  |  | 0.24 | 0.24 |  |  |  | 28648 | 29955 | 31050 |  |  | 1 | 1 | 10 |  |  | https://octopart.com/opatz8j6/a1 | https://octopart.com/opatz8j6/a1 | https://octopart.com/opatz8j6/a1 |  |  | Mouser | 594-K221K15X7RF5TL2 | Tape & Reel | 0.24 | 0.72 | 0.72 | 29955 | 1 | https://octopart.com/opatz8j6/a1
ECA-1HHG2R2I | 1 | Panasonic | ECA-1HHG2R2I | https://octopart.com/eca-1hhg2r2i-panasonic-12553061 | Cap Aluminum Lytic 2.2uF 50V 20% (5 X 11mm) Radial 2.5mm 18mA 1000h 105C Automotive Ammo |  | C9 |  | Production (Last Updated: 3 years ago) | 21w | Compliant | 1 | P19525CT-ND | 667-ECA-1HHG2R2I | 74AK7354 | ECA-1HHG2R2I |  | Cut Tape | Tape & Reel |  | Bulk |  | 0.27 | 0.26 |  |  |  | 12954 | 4884 | 5910 | 2000 |  | 1 | 1 | 5 | 2000 |  | https://octopart.com/opatz8j6/a1 | https://octopart.com/opatz8j6/a1 | https://octopart.com/opatz8j6/a1 | https://octopart.com/opatz8j6/a1 |  | Mouser | 667-ECA-1HHG2R2I | Tape & Reel | 0.26 | 0.26 | 0.26 | 4884 | 1 | https://octopart.com/opatz8j6/a1
K104K15X7RF5UH5 | 2 | Vishay | K104K15X7RF5UH5 | https://octopart.com/k104k15x7rf5uh5-vishay-40993312 | Cap Ceramic 0.1uF 50V X7R 10% Through Hole 5mm 125°C Ammo Pack |  | C8, C46 |  |  | 17w | Compliant | 2 | BC5229CT-ND | 594-K104K15X7RF5UH5 |  |  |  | Cut Tape | Ammo Pack |  |  |  | 0.26 | 0.26 |  |  |  | 35561 | 70148 |  |  |  | 1 | 1 |  |  |  | https://octopart.com/opatz8j6/a1 | https://octopart.com/opatz8j6/a1 |  |  |  | DigiKey | BC5229CT-ND | Cut Tape | 0.26 | 0.52 | 0.52 | 35561 | 1 | https://octopart.com/opatz8j6/a1
K331K15X7RF53L2 | 11 | Vishay | K331K15X7RF53L2 | https://octopart.com/k331k15x7rf53l2-vishay-42623274 | Ceramic Capacitor, Multilayer, Ceramic, 50V, 10% +Tol, 10% -Tol, X7R, 15% TC, 0.00033uF, Through Hole Mount |  | C5, C27, C28, C29, C30, C31, C33, C34, C35, C36, C37 |  |  | 17w | Compliant | 11 | BC5150-ND | 594-K331K15X7RF53L2 |  |  |  | Bulk | Bulk |  |  |  | 0.143 | 0.102 |  |  |  | 22142 | 34228 |  |  |  | 1 | 1 |  |  |  | https://octopart.com/opatz8j6/a1 | https://octopart.com/opatz8j6/a1 |  |  |  | Mouser | 594-K331K15X7RF53L2 | Bulk | 0.102 | 1.1219999999999999 | 1.1219999999999999 | 34228 | 1 | https://octopart.com/opatz8j6/a1
K103K10X7RF5UH5 | 20 | Vishay | K103K10X7RF5UH5 | https://octopart.com/k103k10x7rf5uh5-vishay-44280222 | Multilayer Ceramic Capacitor, 0.01 uF, 50 V, ï¿½ 10%, X7R, Radial Leaded |  | C2, C3, C4, C10, C11, C12, C13, C14, C15, C16, C17, C18, C19, C22, C24, C26, C32, C38, C39, C40 |  |  | 17w | Compliant | 20 | BC2662CT-ND | 594-K103K10X7RF5UH5 | 92K1095 |  |  | Cut Tape | Ammo Pack |  |  |  | 0.16 | 0.101 | 0.04 |  |  | 43219 | 32443 | 8363 |  |  | 1 | 1 | 1 |  |  | https://octopart.com/opatz8j6/a1 | https://octopart.com/opatz8j6/a1 | https://octopart.com/opatz8j6/a1 |  |  | Newark | 92K1095 |  | 0.04 | 0.8 | 0.8 | 8363 | 1 | https://octopart.com/opatz8j6/a1
ECE-A0JKA101I | 1 | Panasonic | ECE-A0JKA101I | https://octopart.com/ece-a0jka101i-panasonic-15327038 | Cap Aluminum 100uF 6.3V 20% (5 X 7mm) Radial 2.5mm 71mA 1000 hr 85°C Ammo Pack |  | C1 |  |  | 21w | Compliant | 1 | 10-ECE-A0JKA101ICT-ND | 667-ECE-A0JKA101I |  | ECE-A0JKA101I |  | Cut Tape | Tape & Reel |  | Bulk |  | 0.25 | 0.24 |  |  |  | 761 | 3609 |  | 6776 |  | 1 | 1 |  | 2000 |  | https://octopart.com/opatz8j6/a1 | https://octopart.com/opatz8j6/a1 |  | https://octopart.com/opatz8j6/a1 |  | Mouser | 667-ECE-A0JKA101I | Tape & Reel | 0.24 | 0.24 | 0.24 | 3609 | 1 | https://octopart.com/opatz8j6/a1
K153K10X7RF5UH5 | 2 | Vishay | K153K10X7RF5UH5 | https://octopart.com/k153k10x7rf5uh5-vishay-44033224 | Multilayer Ceramic Capacitors MLCC - Leaded 15000pF 50V 10% X7R 5mm LS |  | BC1, BC2 |  |  | 17w | Compliant | 2 | BC2671CT-ND | 594-K153K10X7RF5UH5 |  |  |  | Cut Tape | Ammo Pack |  |  |  | 0.24 | 0.24 |  |  |  | 18058 | 15044 |  |  |  | 1 | 1 |  |  |  | https://octopart.com/opatz8j6/a1 | https://octopart.com/opatz8j6/a1 |  |  |  | DigiKey | BC2671CT-ND | Cut Tape | 0.24 | 0.48 | 0.48 | 18058 | 1 | https://octopart.com/opatz8j6/a1
GKG30015 | 1 | Panasonic | GKG30015 | https://octopart.com/gkg30015-panasonic-120079986 | Cap Trimmer 6.5-30PF 100V Th |  | TC1 |  |  | 22w |  | 1 | 2447-GKG30015-ND |  |  |  |  | Bulk |  |  |  |  | 1.32 |  |  |  |  | 15739 |  |  |  |  | 1 |  |  |  |  | https://octopart.com/opatz8j6/a1 |  |  |  |  | DigiKey | 2447-GKG30015-ND | Bulk | 1.32 | 1.32 | 1.32 | 15739 | 1 | https://octopart.com/opatz8j6/a1

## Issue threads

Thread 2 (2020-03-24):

some KiCad symbols missing

mluna0101, 2020-03-24:
The component FC1 is missing it's symbol. Motherboard-rescue:Ferrite_Core-Schematic not found.

As well as DA1, DA2, DA3 and D4. "Schematic" library not found.

Redherring32, 2020-03-25:
The issue is fixed now in the latest commit (A fresh clone should open the schematic without any setup.), it was caused by lack of relative paths, and the latest schematic library not being commited.

mluna0101, 2020-03-25:
See no issues so far. Thanks you!

Closed 2020-03-25.

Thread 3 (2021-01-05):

BOM could highlight X1 is NTSC/PAL dependent

vb216, 2021-01-05:
Hi,

Trying to build a NES from scratch based on your board (thanks for putting that out there), and getting a pretty broken video signal on power on. I saw your comment on nesdev (https://forums.nesdev.com/viewtopic.php?f=9&t=21018&hilit=opentendo&start=15) that you were working on an updated BOM, and after digging into it some more I suspect part of my problem might be I've gone for the PAL UA6527P and UA6528P chips, and didn't realise I should adjust the clock to match.

If you're releasing a new BOM sometime, could be worth marking that X1 should match the PAL/NTSC choice? Unfortunately looks harder to find a 26.601712mhz clock so my PAL choice doesn't seem such a great move.

You've probably spotted it already, but I think there's a 20k resistor listed in the BOM for R8 when it should be a 12k too, from the board marking?

Thanks again, has been fun building it so far!

Redherring32, 2021-01-07:
Hi!
Thank you for your feedback.

Regarding the BOM yes I am trying to put out a fixed BOM, though I haven't had as much time to work on this type of thing as of late, I'm not sure how the BOM errors occured honestly, the BOM was generated from my schematic, which is correct, I suspect some sort of software bug was at play

As for stating the regional dependence in the BOM; that's not really practical/feasible, however I can put it in the release description.

Thank you for your interest in my work!

vb216, 2021-01-07:
Cool that all makes sense, yeah as you say probably just needs a line where you're talking about sourcing the CPU+PPU to match the X1 sourced. In hindsight kind of obvious I guess, but its an interesting learning curve!
Thanks again for the work on the board and making it an open source contribution.

vb216, 2021-01-23:
Thanks for the new commits

Closed 2021-01-23.

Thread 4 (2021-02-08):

Recommended Printer for Board?

dustinschultz, 2021-02-08:
Hi,

This isn't an issue but I didn't have any other way to contact you.

Do you have a recommended place to print the PCB? I know there are several out there but looking for a recommendation (e.g. where you've printed it before) so it will be printed well.

Thanks,
Dustin

Redherring32, 2021-02-08:
I personally go with JLCPCB as they're cheap and high quality, though I think some people use PCBWay for it as well.

For future reference if anyone else sees this; I can also be contacted through Twitter: "@ redherring32" and I also have an email in the "CONTRIB.txt" file in the repo.

Thanks for your interest in my work!

Closed 2021-02-08.

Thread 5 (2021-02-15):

R13 - Wrong value ?

pep3175, 2021-02-15:
I wasn't able to boot up any game until I change R13. On the schematics and on the board silkscreen you mention 1.2k for R13.

On my original board I have 150k for R13.

I managed to boot it up with 150k.

pep3175, 2021-02-15:
I just checked your picture : https://camo.githubusercontent.com/07663c0c9fcb0e95c5505d66159466bb3d674cb9014f4548a6f51fd7f6c98c54/68747470733a2f2f692e696d6775722e636f6d2f6e515036426f4d2e6a7067

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

It seems you also use a 150k resistor for R13

Redherring32, 2021-02-15:
I re-checked everything and you are correct, that is indeed supposed to be 150K.
I have put up a commit that fixes that, and I have updated the schematic/BOM/gerbers in the V1.2 release to fix this as well.

Thank you for bringing this to my attention!

Closed 2021-02-15.

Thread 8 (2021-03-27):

Cartridge Connector Footprint Flipped

ryancole38, 2021-03-27:
Hi, first of all thanks for all of your hard work!  I'm using the footprint for the cartridge connector in a project, and when laying out the PCB, I noticed that the footprint for the cartridge connector seems to have one side reversed.  According to [the nesdev wiki page](https://wiki.nesdev.com/w/index.php/Cartridge_connector), pin 1 should be on the other side from pin 37 and pin 36 should be on the other side from pin 72.  As it currently stands, the footprint is aligned such that pins 36 and 37 are directly on the opposite side from each other.  Also, pin 38 seems to be labeled 28 (although this could just be an issue on my end).

I thought it might just be a difference in numbering, but the the CIC connections are supposed to be right across from each other, but on my PCB they are on opposite halves of the board.

It's entirely possible that I'm simply using the footprint wrong since I'm very new to Kicad, but if this is the case I can update the footprint with my fix.

Redherring32, 2021-03-27:
I can confirm that the footprint is correct on my end:
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

ryancole38, 2021-03-27:
Interesting- that's what I expect to see as well.  Let me do a fresh pull and start up a new project to see if I can duplicate what my issue was.

ryancole38, 2021-03-27:
Here's what I see if I open up the footprint in the footprint editor:

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

Redherring32, 2021-03-27:
Just did a fresh clone and it's still correct on my end:
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

ryancole38, 2021-03-29:
Huh.  I still haven't figured out why it shows up the way it does for me.  Probably user error.  Even looking at the footprint that the motherboard references it shows up wrong, but the motherboard PCB shows up correctly.  I'll close the issue and update if I ever figure out what I did.  Thanks for double checking!

Closed 2021-03-29.

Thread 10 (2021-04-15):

BOM Errors and Unused silk screen markings disappeared between 1.1 and 1.2.

muramasatheninja, 2021-04-15:
On V1.1 The following are marked 'unused' R14, R16, C6 and C7, but not on V1.2

TC1, RA2, and R14 are also missing from the BOM.

C4, C6, C7, C21, and C44 are all 220pf. C21 is using a different wider footprint then the others. This can probably be consolidated.

On the schematic and the board C20, C43, and C45 are listed as 51pf. In the BOM though they are listed as 56pf (K560J15C0GF5TL2).

It might also make sense to mark these on the BOM somehow so people know they don't actually need to obtain them.

Redherring32, 2021-08-21:
All issues should now be resolved.
Unused, and parts that can't be obtained from normal suppliers have been removed from the BOM, and footprint width inconsistencies have been resolved.

Regarding the inconsistency of C20, C43, and C45, their rated value on the PCB can't be easily obtained, so the BOM substitutes another value which is within required tolerances. (56pF)

Closed 2021-08-21.

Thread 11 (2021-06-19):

6116SA15TPG alternative

maci0, 2021-06-19:
CY7C128A seems to be a cheaper alternative to the 6116SA15TPG $69SGD vs $5.54SGD for 10.
Looking at the datasheet they seem to be pin and voltage compatible.
Biggest difference I could see is that the CY7C128A is not rated for industrial and military grade ambient temperatures.
I don't expect any OpenTendos to be used on the wing of an airplane mid-flight, so it should be fine.

Redherring32, 2021-06-19:
If you can confirm they work as a replacement I'd gladly update the BOM. :)

Scyllinice, 2023-01-29:
Sorry to bump this a bit, but it looks like the 6116SA15TPG is no longer available at Mouser or Digikey. An available alternative would be nice to have if this situation doesn't change.

Closed 2021-08-21.

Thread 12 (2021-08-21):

[Question] Power module replacement

Baktus79, 2021-08-21:
I have searched everywhere for a power/AV module either as a used one or a board that I can print myself, but it is completely impossible to find. There are some boards out there, but they are not complete or do not work without additional high def expansion cards.

Do you know about something that works with standard mono and composite? Or maybe you made something yourself?

Redherring32, 2021-08-21:
I have designed a replacement, it just needs testing before I open source it.

Baktus79, 2021-08-21:
Thank you for your answer! Amazing work you have done with Opentendo! Then I will wait until you make the power module available.

cacois, 2024-05-29:
Sorry to resurrect a closed thread @Redherring32, but I'm curious - was the power module you mentioned ever completed?

Closed 2021-08-21.

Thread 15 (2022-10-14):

Reset Loop

Inuyashagcn, 2022-10-14:
I just finished the assembly of the Openendo board and I have a reset loop when turning on the console, it only happens with some games like Kirby Adventure or Tetris, but with Super Mario Bros / Duck Hunt and Famicom games (Rockman 3) using an adapter , they work right.
I currently have the CIC chip with Pins 4 and 13 disabled (in fact when I made the mod I cut both pins and it worked on the original board), will it be that I need a new CIC (like NullCIC or another of spare)?

kamoteshake, 2025-01-07:
@Inuyashagcn I know this is more than 2 years old. Were you able to figure this issue out?

kamoteshake, 2025-01-14:
Closing since it's a stale issue and was from an older revision.

Closed 2025-01-14.

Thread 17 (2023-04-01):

C20 value inconsistency between schematic, pcb and bom

Kjubyte, 2023-04-01:
Hi,
in d530f0018b1901474343302d69b92cd2f602043a you changed C20 from 51pF to 220pF in all schematics, but the pcb silk screen and bom still shows 51pF. I guess, this should be also changed to 220pF?

Redherring32, 2023-04-02:
Yes, I have checked my work again to double check, and it being 51pF was an error, it should be 220pF. :)
I thought I had changed the silkscreen to reflect this fix but I guess it slipped through the cracks.

Redherring32, 2023-04-02:
Fixed in https://github.com/Redherring32/OpenTendo/commit/5e7f66dc437d01216686a1833f801d3e9a8801c2

(BOM will also be updated when possible)

Closed 2023-04-02.

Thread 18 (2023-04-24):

Time for version 1.3?

OlivierGrimard, 2023-04-24:
Hi,
   I would like to try this project but I don't have the software to convert the design into Gerber files. The last time the Gerber file was updated was 2 years ago.  Can someone can take the last build from the master to create Gerber files RS-274-X version?

Thank you.

Iceymidgit, 2023-04-26:
this would be great to get

Redherring32, 2023-04-26:
Yes a new release should be coming soon. :)

FrostSSBM, 2023-04-27:
Will the release contain an updated BOM?
Specifically, the WRAM chip (6116SA15TPG) is now out of production and very hard to find.

gabrielBitts, 2023-05-15:
I'm having a same issue with the RA2 which is 6.8k but I can't find it anymore nowere :(

gabrielBitts, 2023-05-15:
> Will the release contain an updated BOM? Specifically, the WRAM chip (6116SA15TPG) is now out of production and very hard to find.

I'm having a same issue with the RA2 which is 6.8k but I can't find it anymore nowere :(

Iceymidgit, 2023-06-18:
any rough eta?

iceyman, 2023-07-23:
Gday mate thought I would see if there has been an update as it has been approx 5 months said you would release an update

oXL0C0Xo, 2024-02-26:
Thank you for this project! I see there have been quite a few changes, and when I try to get the gerber files from the source KiCad complains about a few things. I'm nervous to order the new PCB's as I'm not an expert with this software and dont want to screw anything up. Is there anywhere that the gerber files with the improvements have been released? Would like to get a few boards made. Thanks!

iceyman, 2024-04-16:
any updates ?

kamoteshake, 2024-06-26:
I'm also interested in the latest gerber file and BOM.

Redherring32, 2024-06-26:
An update is coming very soon, but whether it has BOM updates is TBD currently, depends if I can find alternatives for some of the things that went EOL.

Stay tuned. :)

Y2K-x, 2024-06-27:
> any updates ?

If I may add as an impartial 3rd party - Github Issues are no place to be begging for updates on a project periodically. Issues are meant for reporting, discussing, and collaborating on bugs, WIP features, or feature requests, and this fits none of those criteria. Personally I'd recommend you get in contact with any project maintainers more directly in the future, or in this case, you can join Redherring's Discord server for progress updates & discussion on TinyTendo & his other projects.

oXL0C0Xo, 2024-06-27:
Where is there a link to a Discord server, or a way to contact the project maintainer?

> > any updates ?
>
> If I may add as an impartial 3rd party - Github Issues are no place to be begging for updates on a project periodically. Issues are meant for reporting, discussing, and collaborating on bugs, WIP features, or feature requests, and this fits none of those criteria. Personally I'd recommend you get in contact with any project maintainers more directly in the future, or in this case, you can join Redherring's Discord server for progress updates & discussion on TinyTendo & his other projects.

Where is there a link to a Discord server, or a way to contact the project maintainer?

kamoteshake, 2024-07-03:
> Where is there a link to a Discord server, or a way to contact the project maintainer?

After a quick Google search. I found [this](https://linktr.ee/Redherring32).

iceyman, 2024-07-03:
> > Where is there a link to a Discord server, or a way to contact the project maintainer?
>
> After a quick Google search. I found [this](https://linktr.ee/Redherring32).

lol quick search is about 1 week later :P

oXL0C0Xo, 2024-07-03:
What did you search google for to find that Discord? I tried a bunch of stuff and it never came up. Also, might not be a bad idea to mention that it exists somewhere on this repository. I hadn't ever even used Discord before, or knew that was even a possibility.

kamoteshake, 2024-07-03:
> lol quick search is about 1 week later :P

hahahaha. I forgot about this thread. I promise, It took me less than 3 mins to find it. 🤣

> What did you search google for to find that Discord? I tried a bunch of stuff and it never came up. Also, might not be a bad idea to mention that it exists somewhere on this repository. I hadn't ever even used Discord before, or knew that was even a possibility.

Just did "Redherring32 Discord Server". I know.

kamoteshake, 2024-07-03:
well. I know this is off topic but #21 just adds a discord badge on the README.

kamoteshake, 2025-01-08:
Sorry it took but it's finally here! [v1.4](https://github.com/Redherring32/OpenTendo/releases/tag/V1.4) and [v1.4_modded](https://github.com/Redherring32/OpenTendo/releases/tag/V1.4-Modded).

We also updated the repo to make it a tad user friendly. We tried updating the BOM as much as we could. You can now see it in the repo but we also kept it in the release.

Again, sorry it took a while. There were a lot of testing especially with the updated BOM. We'll be closing this issue since we did a new release for v1.4

Closed 2025-01-08.

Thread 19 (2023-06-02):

RA2 substitute

gabrielBitts, 2023-06-02:
I accidentally broke the original 5 pin 6.8kx4 resister array from the original board, but I'm not finding this component anywhere over the internet.
There is any substitute of this component that I can use?

Redherring32, 2023-06-02:
This should work as a drop in replacement, will add it to the BOM in the next version.

https://www.mouser.com/ProductDetail/Bourns/4605X-101-682LF

Closed 2023-06-02.

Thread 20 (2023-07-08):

6116SA15TPG replacement

ceddr69, 2023-07-08:
Hello,

Can the 6116SA15TPG be replaced with the original Nes Ram ? It's very hard (and expensive) to find now ... I have sanyo lc3517bs-15 available on a damaged nes board.

Thanks in advance,

jparks1980, 2023-10-13:
Yes I am also having difficulty locating 6116SA15TPG.  Nobody seems to have any.  I see there are other chips of the same 6116 type but am unsure if they are compatible.  Has anyone found an alternative to this or a place that can still source the 6116SA15TPG?

jparks1980, 2023-10-14:
Im unsure but I suspect the 6116SA15SOG8 is the same exact chip as the 6116SA15TPG except the 6116SA15SOG8 is SMD and the other is through the board.  Basically a more modern version.  I think designers are moving away from through the board components.  If 6116SA15SOG8 is the same, an adapter board could definitely be made.  Of course I am only guessing at this point.

Redherring32, 2023-10-16:
The RAM from an original OEM motherboard can be used on OpenTendo, as well as any of the chips.
No issues at all with doing that. :)

I haven't had much time to look into it myself, but if someone finds an active part number for RAM I'd be happy to add it to the BOM.

Closed 2023-10-16.

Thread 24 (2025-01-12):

No video synch opentendo + merlin gen2 av board

danyboy666, 2025-01-12:
I have an issue where i can get nk video other than what you seen in pics. I'm really not sure where to look at the only thing I haven't tried is swapping with an original rf av mod. Both cpu/ppu tested ok in a test board as well as both ram chips. I've tested all 3 transistors even swapped them.out to be sure. Not sure what i can do next. I'd rather not desoler the av module at thus time. Voltages are fine. Sorry if this isn't the right place for this feel free to close the issue. Thanks.

[20250112_094451.jpg](https://github.com/user-attachments/assets/857dbc77-9c57-49ea-b260-5a3c6f7f903f)

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

kamoteshake, 2025-01-13:
At this point, I would test it with the OEM power module. Just dab a small solder on one tab just to connect the ground and it will be easier to desolder later.

danyboy666, 2025-01-13:
It only took three days of screwing around.... I should have tested with and original power module at first. 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

It's working even without the proper trimmer cap. Something is up with the power module I was sold I'm not sure what. I think i'll retest it just to be sure but it's almost certain it's that. I'm kinda glad it wasn't my opentendo build lol.

kamoteshake, 2025-01-13:
Love the way you tested the original power module. 😅 Good luck with the power module troubleshooting.

I'll close this issue as since OpenTendo is working fine.

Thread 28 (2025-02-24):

Sync issue when using lava RGB 1.1

danyboy666, 2025-02-24:
Hi,

I've been troubleshooting an issue with the lava RBG board version 1.1. It seems the Lattice code depends on PPU CLK line being initialize at the right time. If using a 74HC139 to handle M2 it seem to misshandle to critical calls and send whatever eronious data to the PPU before the game the CPU is really in a ready state. I did not test did more so i'm really sorry for the lack of technical lingo here but installing a 74LS139 solve the issue right away.

Before

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

After

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

Both over composite.

Ive tested with two opentendo board with your BOM and one which i've ported from and OEM board. The OEM one did not have the issue. This is pretty much how i've spotted the issue. I don't think this is an issue with eTim's new rev 4 RGB board. It might have been in the past but since he's generating his own PPU_CLK the issue would not appear I guess.

danyboy666, 2025-02-26:
Also two other set of logic chips on that board should be LS version. You can't mix LS and HC. But you can mix HCT with HC and LS.

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

The only logic IC that should be HC is the 04.

I'll update my BOM with my findings. You can do whatever you like with this info.

Thanks

danyboy666, 2025-04-28:
I've helped a user which had the same issue with a NESRGB board from etim. The original PCB does say LS. I'd say since it does respect the preservation side and rule out any further issues like it might be a good thing to update the BOM eventually. Sometime HC and LS are interchangeable but other times one can interpret a low from a chip as a high vice-versa. But yeah at least a little note on that chip in particular wouldn't hurt.

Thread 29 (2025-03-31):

Include internet and achievements?

odelot, 2025-03-31:
Hi, I develop an adapter to add internet and RetroAchievements to the original NES (https://github.com/odelot/nes-ra-adapter).

The software is mature, but we need to improve our PCB design to make it more robust and fit in a cartridge size (today we are using a prototype pcb too big we need to let NES opended).

When I shared in the shmups forum https://shmups.system11.org/viewtopic.php?p=1575761#p1575761 , someone suggest incorporating with one version of opentendo.

I would glad help this initiative.

BTW, great work with opentendo! This is great preservation initiative.  Cheers from another NES lover.

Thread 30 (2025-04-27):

Missing BOM Components

nebhead, 2025-04-27:
The below are missing from both the BOM.CSV and the Interactive BOM HTML.

R14 (5.6k Ohm Resistor)
C6, C7 (220pF Ceramic Caps)

The below is missing from the BOM.CSV:

DA2, DA4 - UPA64H*

This may be by design since this is difficult to source, but perhaps we should still include it in the CSV file.

danyboy666, 2025-04-28:
These are unpopulated

R14 (5.6k Ohm Resistor)
C6, C7 (220pF Ceramic Caps)

kamoteshake, 2025-04-28:
DA2 and DA4 is in the [From the OEM NES](https://youtube.com/shorts/TLJ6SRu-Uqo?si=RMK07xkDOZZ-YXBV) section since it is difficult to find new replacements.

nebhead, 2025-04-28:
Thank you all for the clarification(s).  I'll go ahead and close this issue as user error.  That said, maybe we should have a note in the documentation about the unpopulated parts.

Closed 2025-04-28.

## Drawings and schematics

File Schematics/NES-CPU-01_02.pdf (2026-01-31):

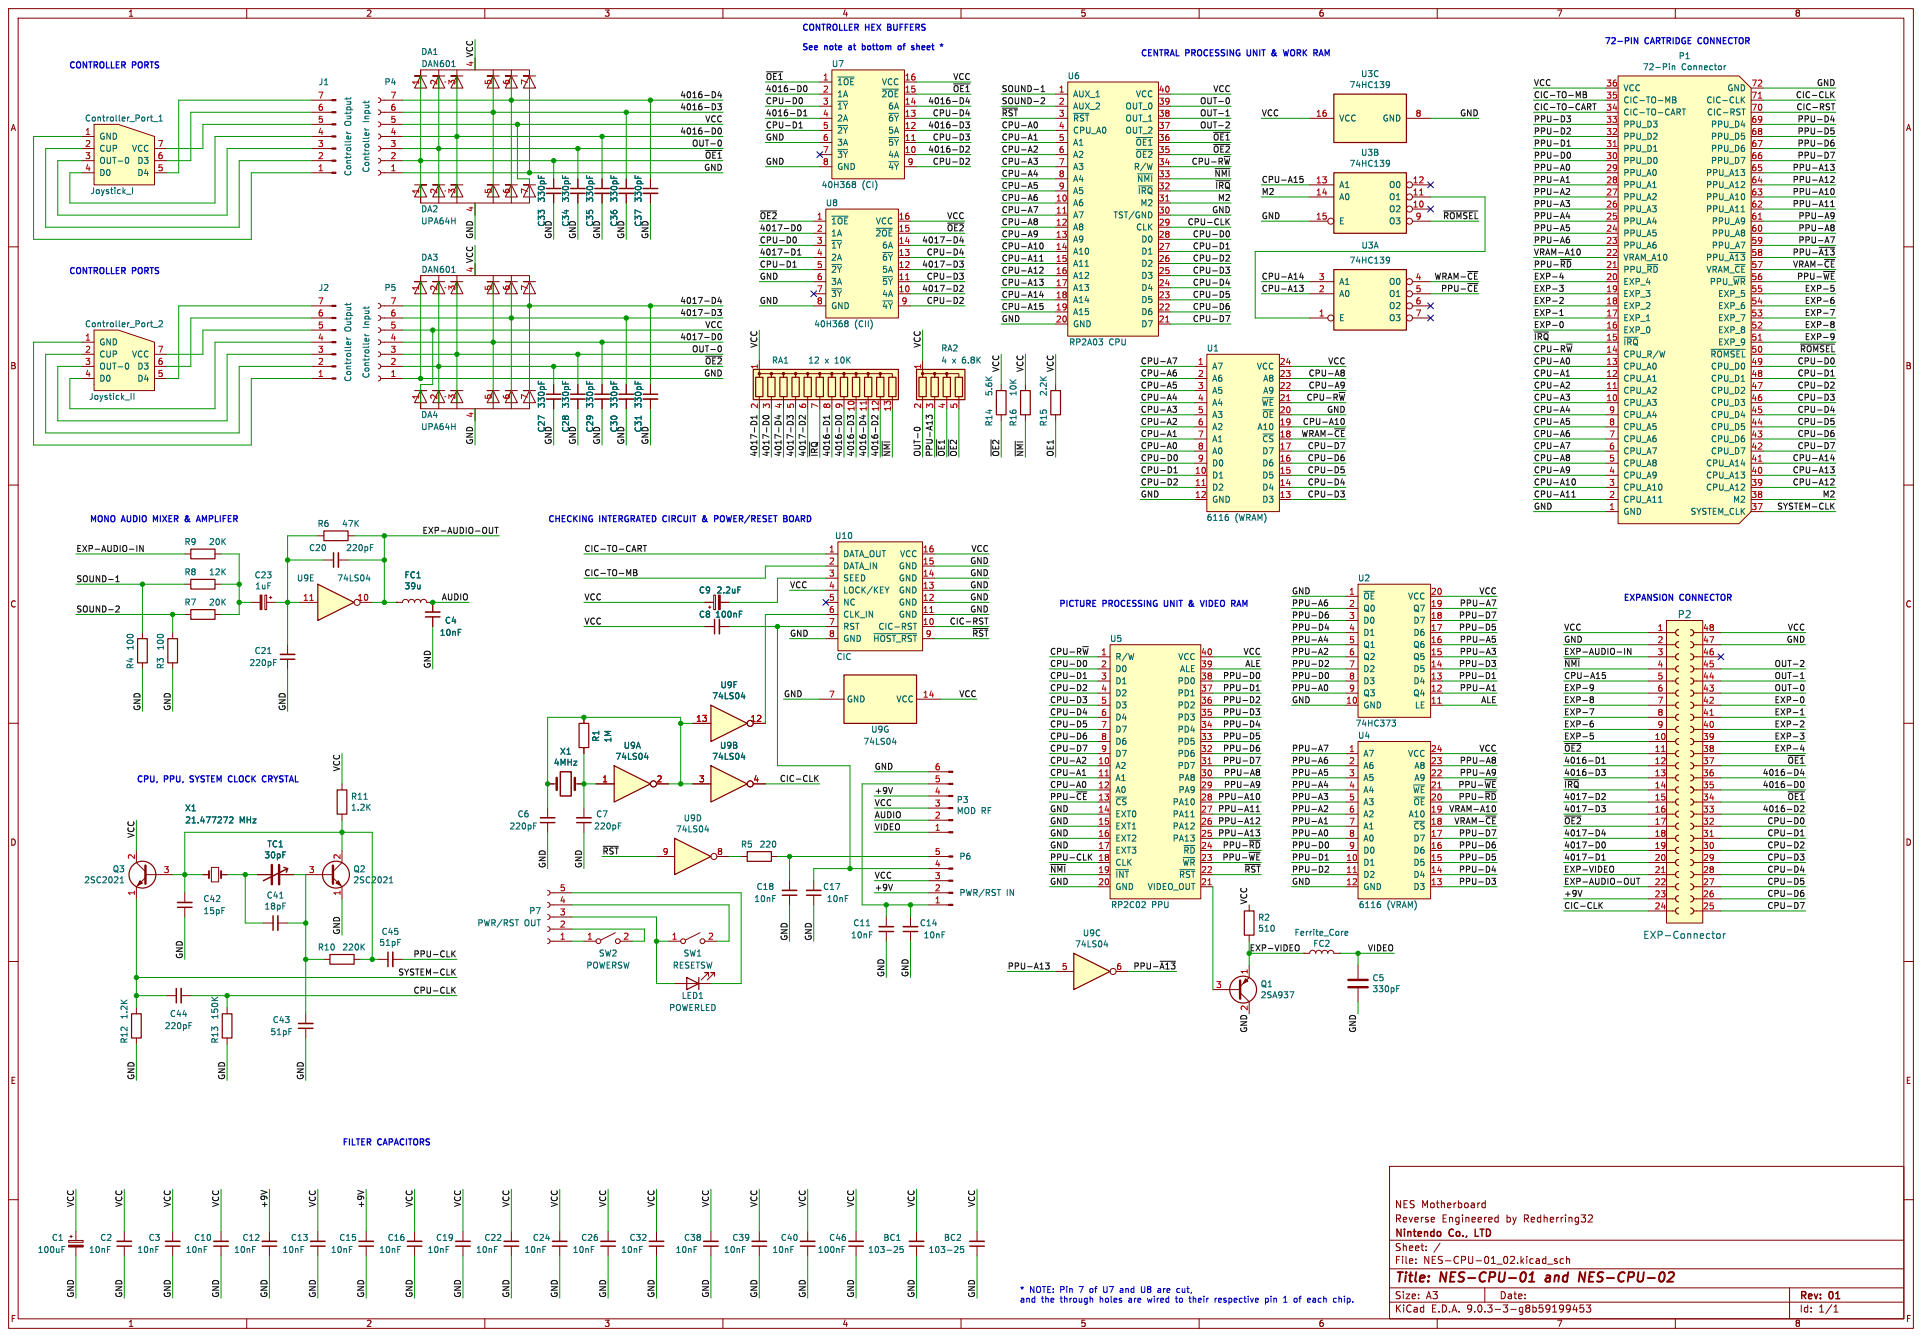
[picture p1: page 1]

CONTROLLER PORTS CONTROLLER PORTS MONO AUDIO MIXER & AMPLIFER

CENTRAL PROCESSING UNIT & WORK RAM

VCC
PPU-A11 PPU-A8 PPU-A7 PPU-A9 CIC-TO-MB

CIC-CLK CIC-RST GND

CPU-D3 CPU-D2 CPU-D1 CPU-D5 CPU-D7M2 CPU-D0 GND

CPU-A8 CPU-A11 CPU-A9 CPU-A10

CPU-A8 CPU-A14 CPU-A13 CPU-D4 CPU-D6 CPU-A7 CPU-A6 GND

EXP-8 EXP-9 ~{ROMSEL} GND

CPU-A8 CPU-A7 CPU-A1 CPU-A2

CPU-A5 CPU-D2 CPU-A0 GND

~{OE2} ~{NMI} VCC GND GND GND

CPU-D5 CPU-D3 GND GND GND GND

CHECKING INTERGRATED CIRCUIT & POWER/RESET BOARD

6116 (WRAM)
PPU-~{WE} PPU-A10 PPU-~{RD} PPU-A13 PPU-D2VCC

EXP-2 EXP-3 EXP-4 EXP-1 EXP-0 OUT-1 OUT-2 EXP-AUDIO-OUT AUDIO

CIC-TO-MB CIC-TO-CART

VRAM-~{CE} VRAM-A10 PPU-D5 PPU-D7
PPU-A1 PPU-D1 PPU-A5 PPU-~{RD}
PPU-A9 PPU-~{WE} PPU-A3ALE

PICTURE PROCESSING UNIT & VIDEO RAM

PPU-A6 GND
PPU-D0 PPU-A7 PPU-A6 PPU-A4

CPU, PPU, SYSTEM CLOCK CRYSTAL

4016-D0 EXP-AUDIO-OUT GND

PPU-CLK
SYSTEM-CLK CPU-CLK

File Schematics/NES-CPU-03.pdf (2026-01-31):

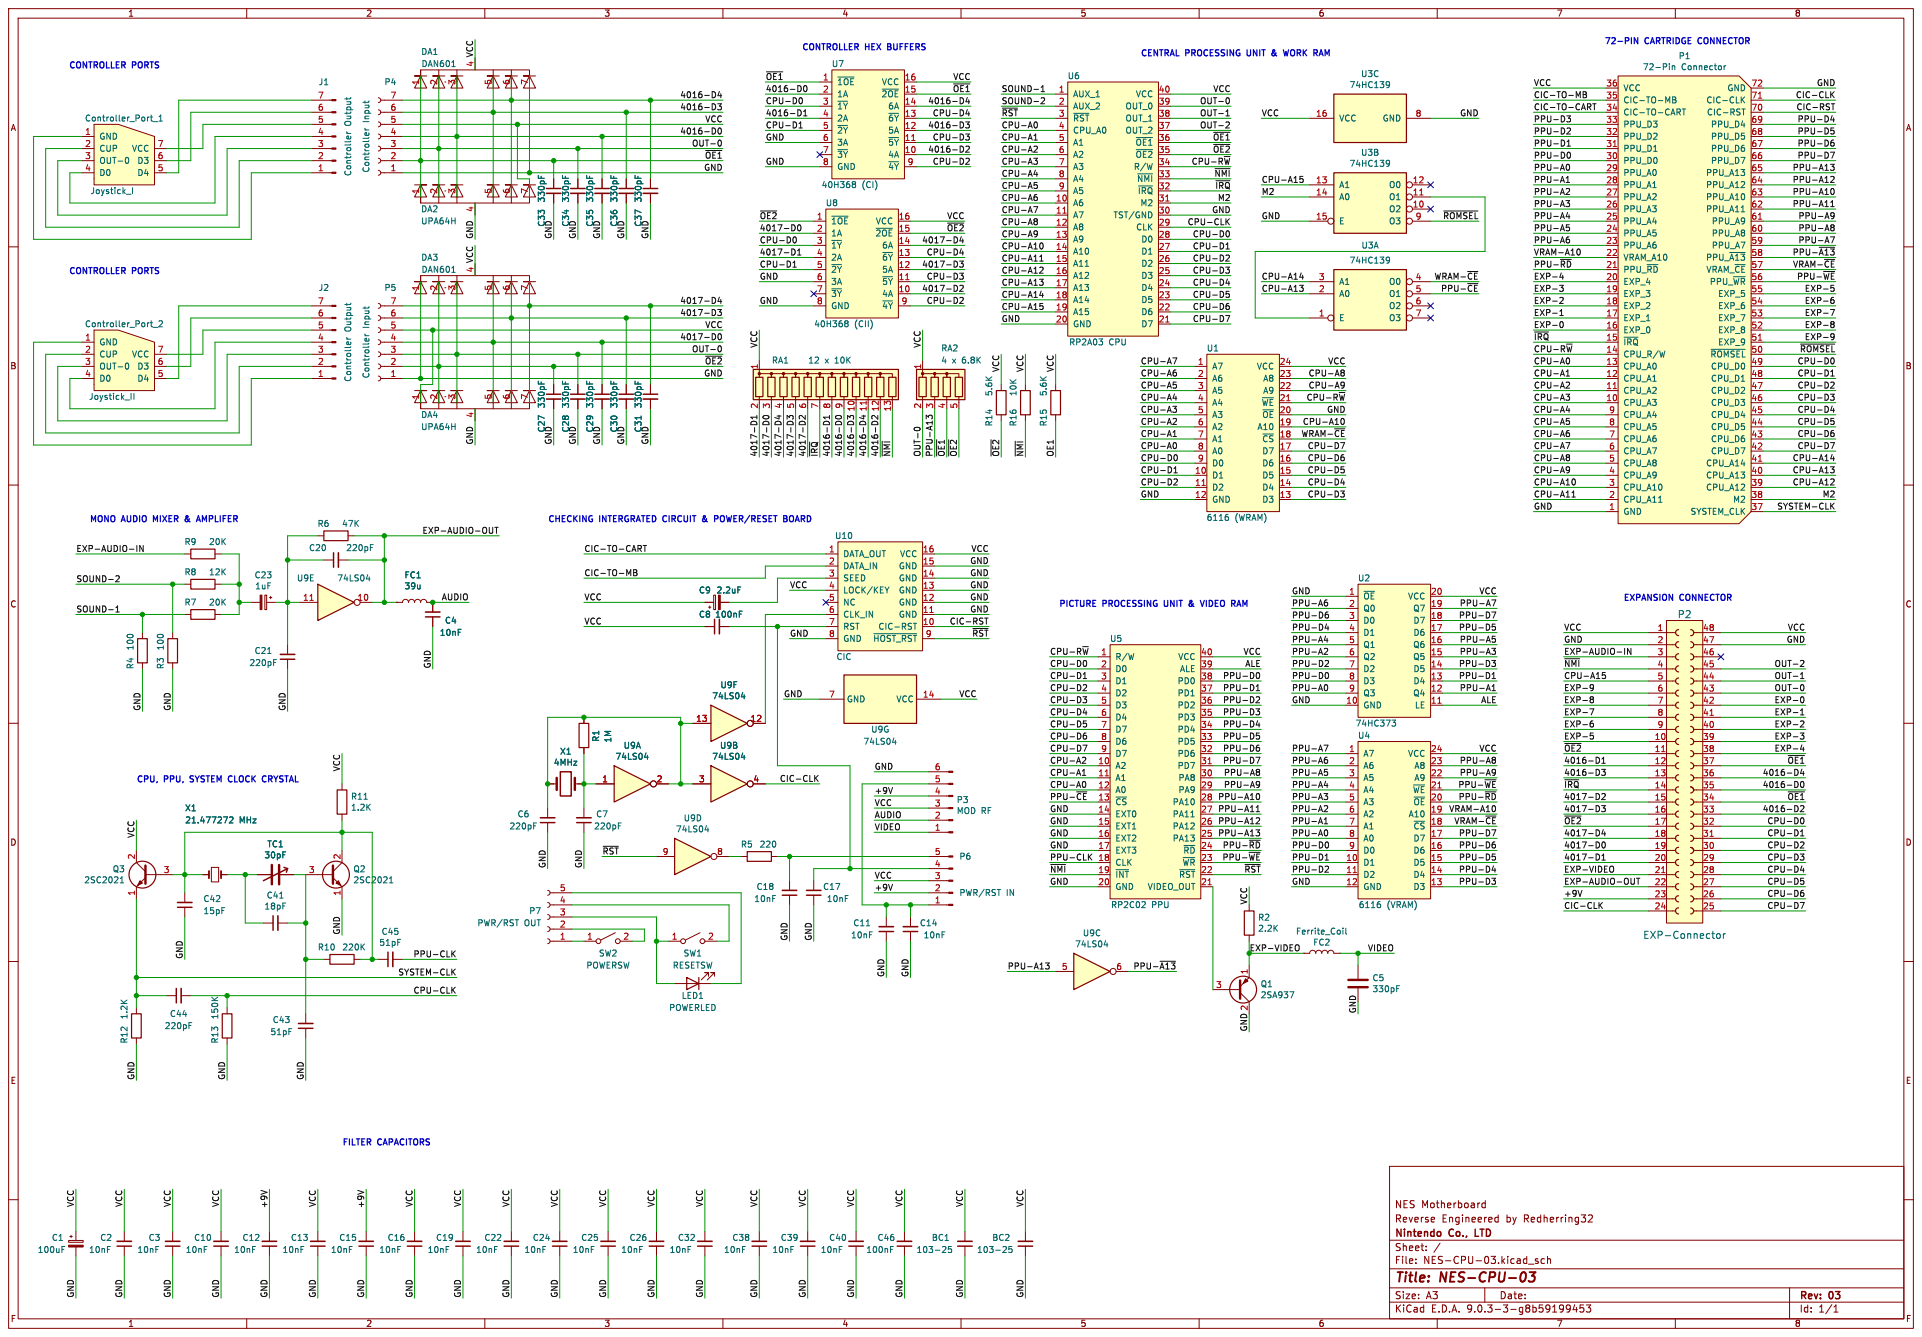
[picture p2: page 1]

CONTROLLER HEX BUFFERS MONO AUDIO MIXER & AMPLIFER

~{IRQ} EXP-0 CPU-A6 CPU-A7 CPU-A4 CPU-A5 CPU-A3 CPU-A2 CPU-A0 CPU-A1 PPU-A4 PPU-D0 PPU-D2 PPU-A0 PPU-D1 VCC

CENTRAL PROCESSING UNIT & WORK RAM
CPU-D2 CPU-D4 GND

SOUND-2 ~{RST} CPU-A2 SOUND-1 CPU-A0 CPU-A1 GND VCC
OUT-0 OUT-1 GND

PPU-D3 CIC-TO-CART CIC-TO-MB

CPU-D1 GND
CPU-R~{W} VCC GND ~{OE1} GND

PPU-~{A13} PPU-A7 PPU-A8 PPU-A9 GND

CONTROLLER PORTS
CPU-A13PPU-D0 CPU-D6 CPU-D7 EXP-AUDIO-IN

PPU-~{WE}
CPU-D7 CPU-D6 CPU-A14 CPU-D5 CPU-D4 CPU-A12M2 CPU-A13 CPU-D0 EXP-9 EXP-8 ~{ROMSEL} VCC

VCC
EXP-8 CPU-A8 CPU-A9 VCC

CPU-A9 VCC GND GND

WRAM-~{CE} CPU-A10 CPU-R~{W} GND

CPU-D0 CPU-A0 VIDEO GND

CPU-D3 CPU-D5 CPU-D4 VCC

CHECKING INTERGRATED CIRCUIT & POWER/RESET BOARD

CPU-D2 CPU-D3 GND GND GND GND GND

PICTURE PROCESSING UNIT & VIDEO RAM

4016-D4 EXP-2 ~{OE1} EXP-3 EXP-4 EXP-AUDIO-IN

FILTER CAPACITORS CPU, PPU, SYSTEM CLOCK CRYSTAL

Id: 1/1 Title: NES-CPU-03

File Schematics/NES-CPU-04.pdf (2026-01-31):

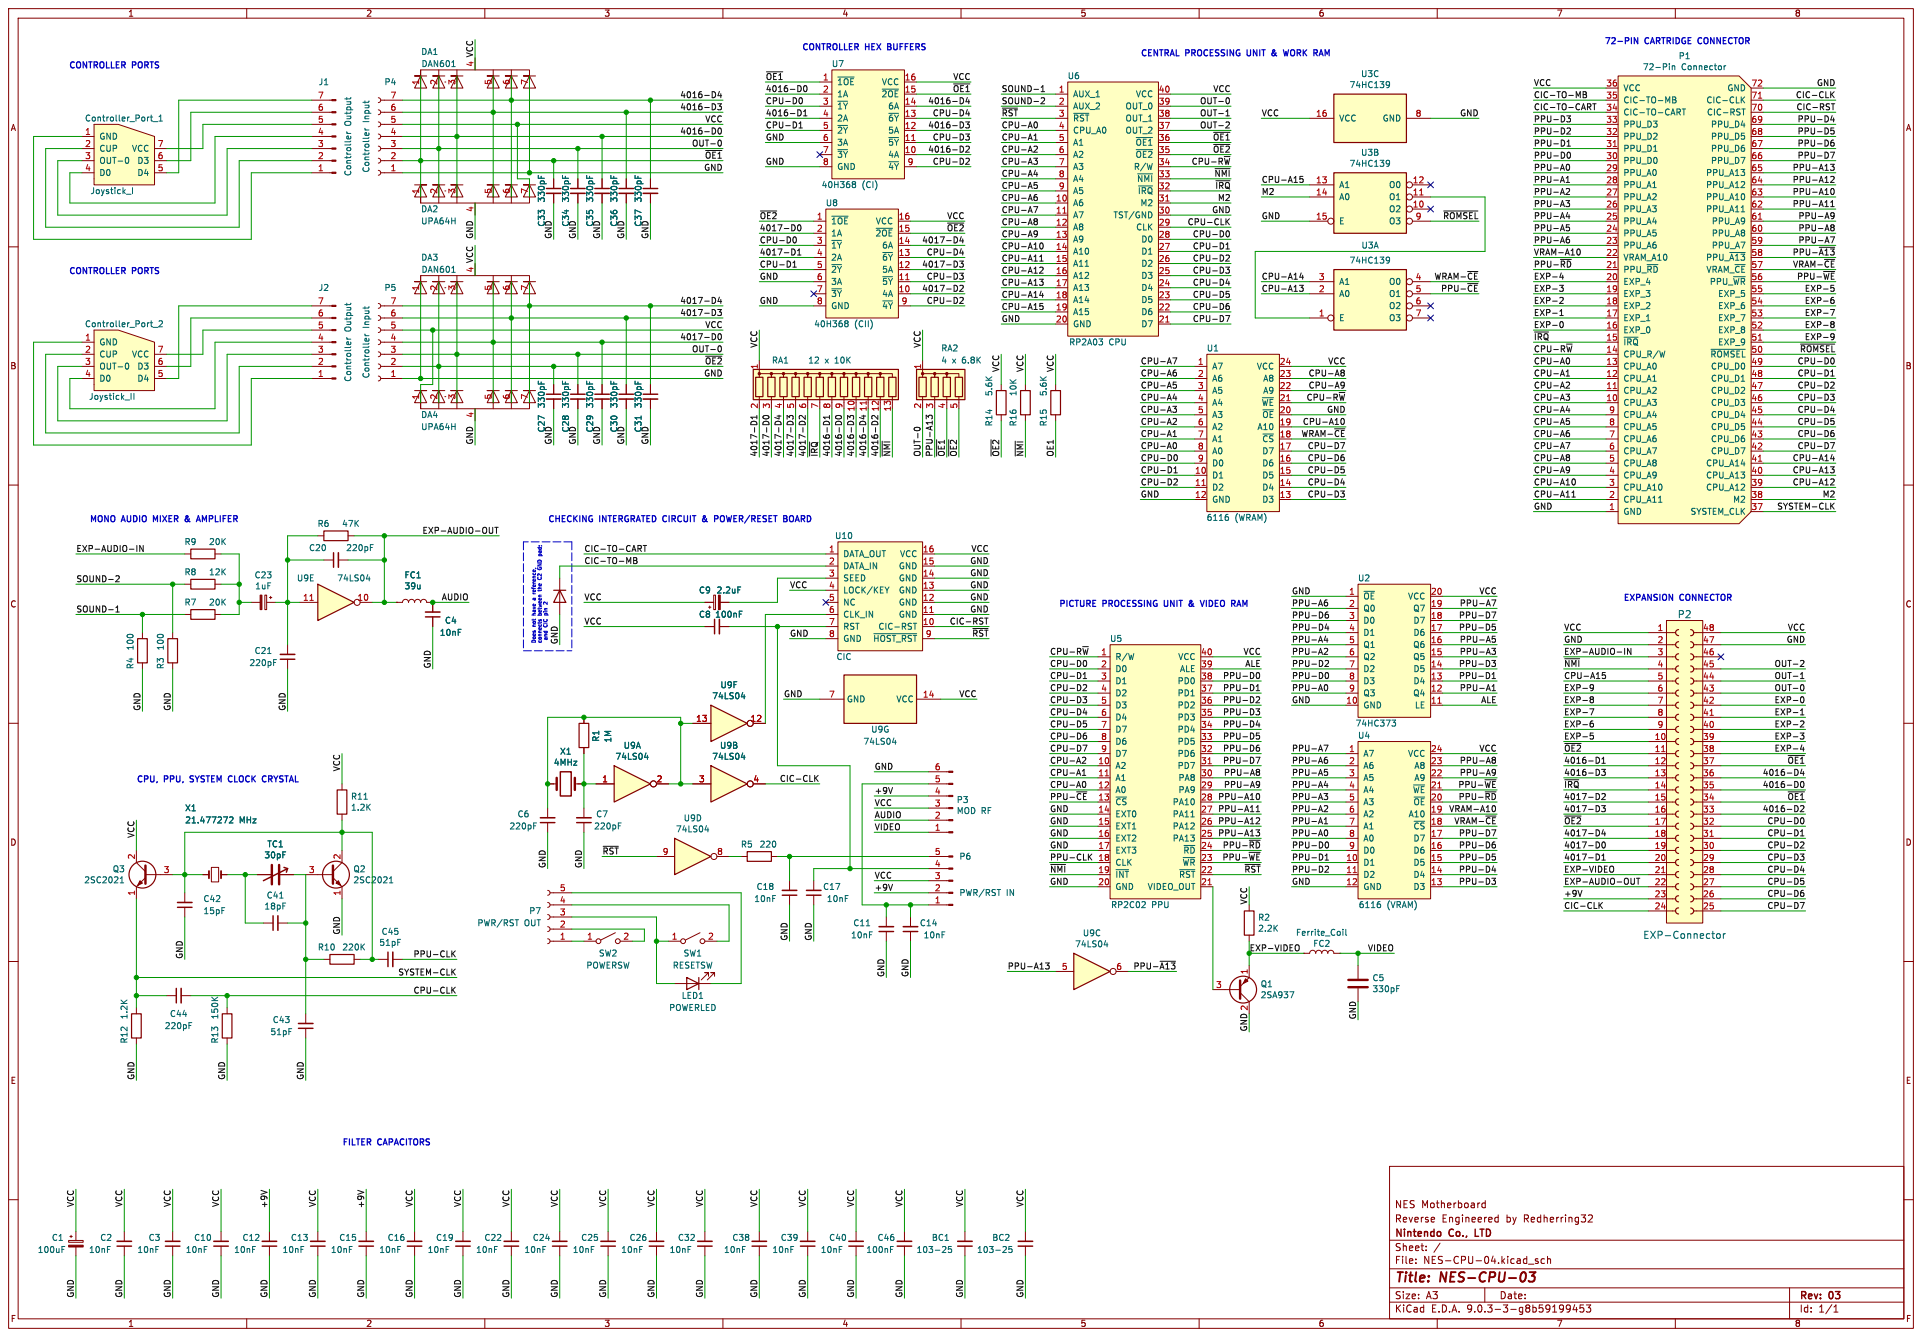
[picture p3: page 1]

~{OE1} 4016-D0 CPU-D0
CIC-TO-MB GND
4016-D1 CPU-D1 GND GND
4016-D3 CPU-D3 CPU-D1 GND

PPU-~{RD} EXP-4 EXP-3 PPU-D1 PPU-D0

CIC-CLK GND VCC

CIC-TO-CART PPU-D3 PPU-D2 PPU-A1 GND
CPU-A0 VCC GND

PPU-A2 PPU-A3 PPU-A4 PPU-A5 PPU-A6 VRAM-A10 ALE

EXP-6 EXP-5 PPU-~{WE} CPU-A2 CPU-A1 CPU-A0 PPU-~{CE}

EXP-0 VCC GND GND GND

CPU-A1 CPU-A0 CPU-D1 CPU-D2 GND

PICTURE PROCESSING UNIT & VIDEO RAM Does not have a reference, connects between the C2 GND pad; and CIC pin 2 FILTER CAPACITORS

PPU-A1 PPU-D1 PPU-D3 PPU-A3 PPU-A5 PPU-D5 PPU-D7 PPU-A7 VCC

PPU-D5 PPU-D6 PPU-D7 VCC

~{NMI} CPU-A15 EXP-9 GND

PPU-CLK CPU-CLK
SYSTEM-CLK

Id: 1/1 Title: NES-CPU-03

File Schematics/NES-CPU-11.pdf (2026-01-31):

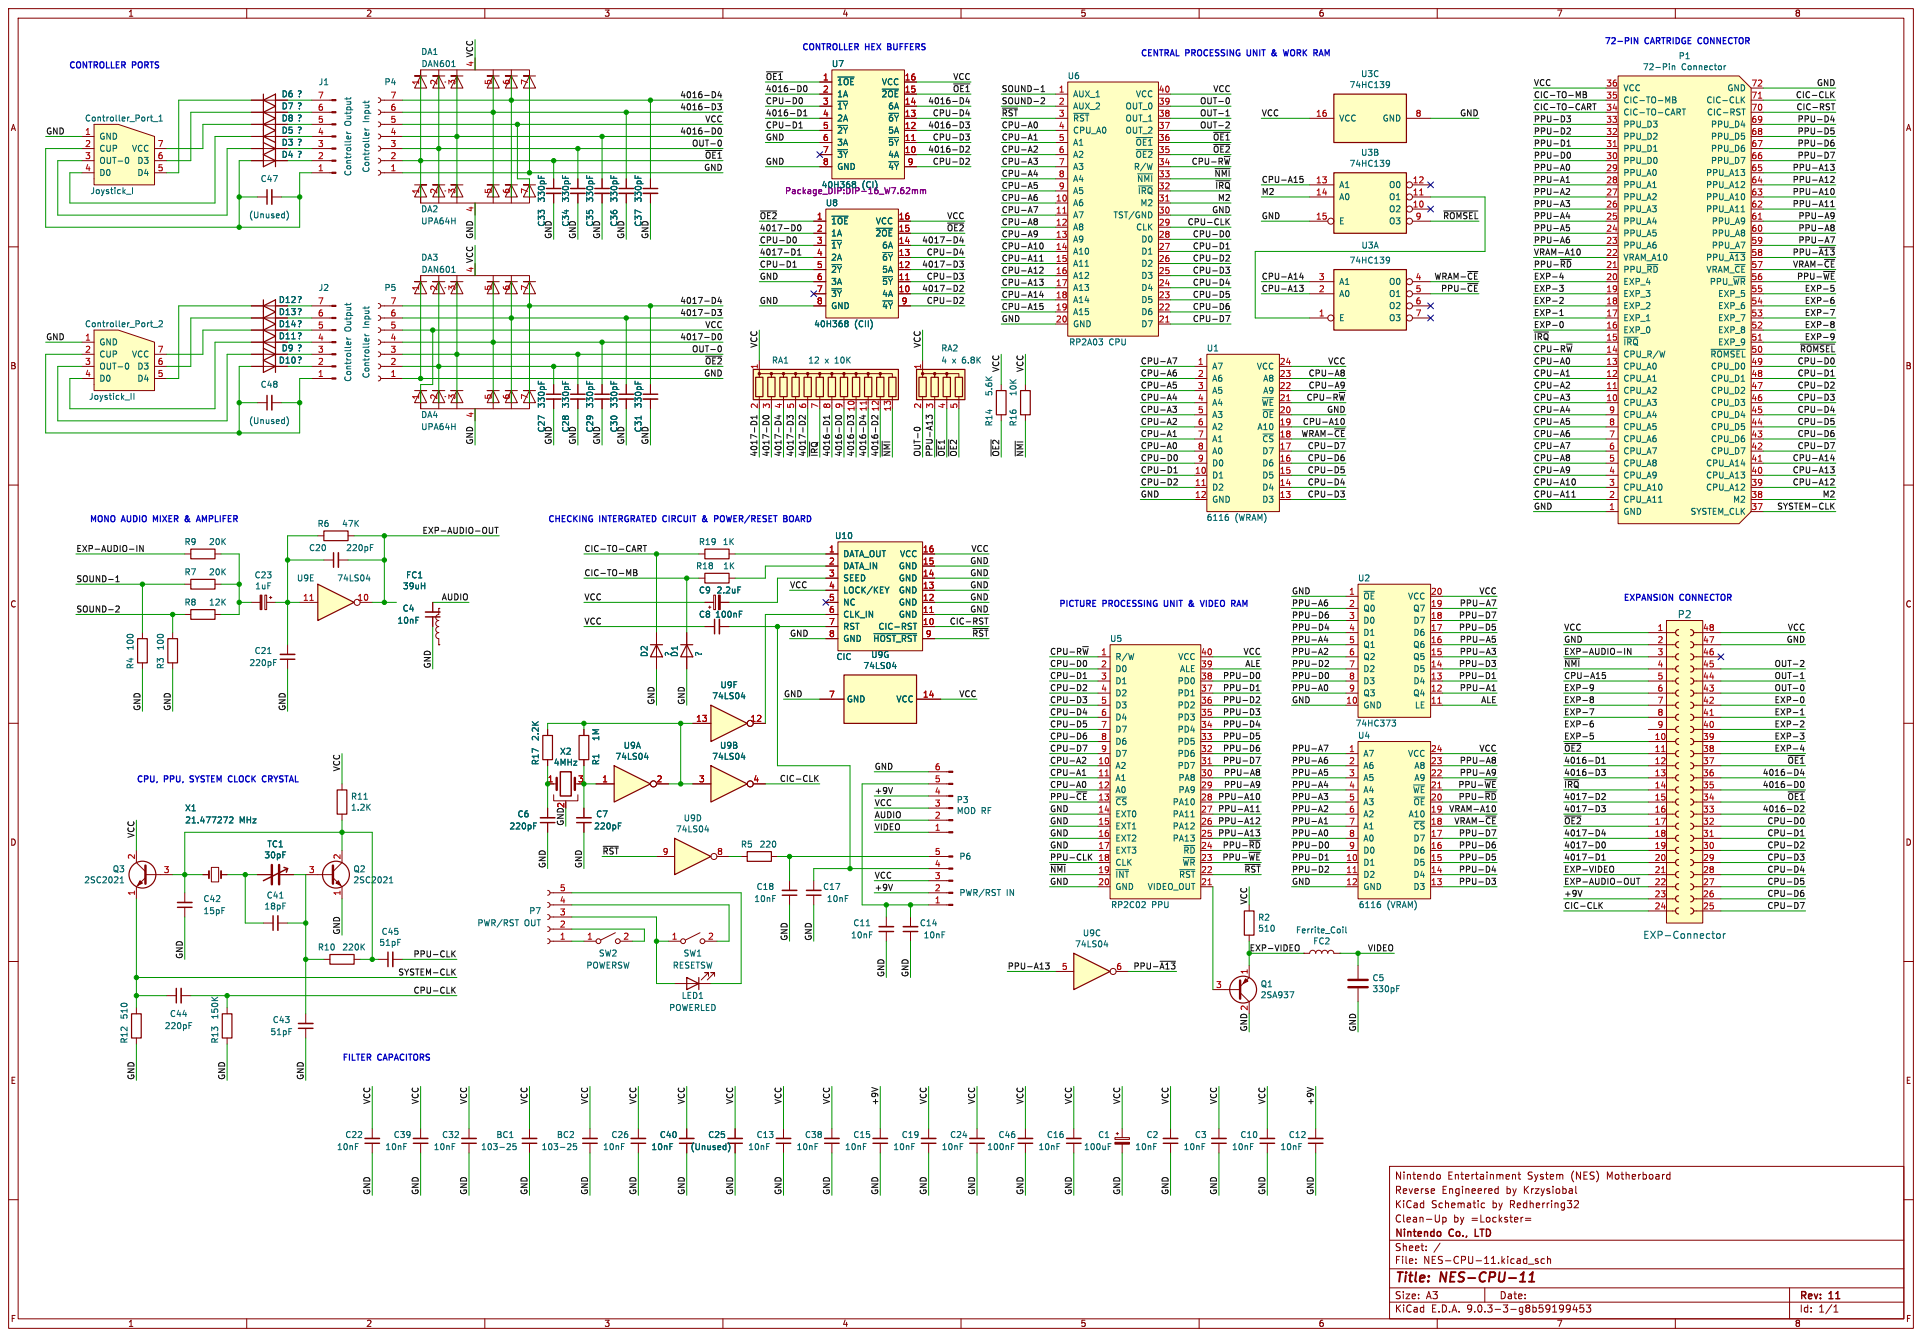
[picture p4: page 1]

CONTROLLER PORTS MONO AUDIO MIXER & AMPLIFER

CONTROLLER HEX BUFFERS CHECKING INTERGRATED CIRCUIT & POWER/RESET BOARD

CENTRAL PROCESSING UNIT & WORK RAM
4016-D3 CPU-D3 VCC

CPU-A13 CPU-A14 CPU-D7 CPU-D6 SYSTEM-CLKM2 CPU-A12 PPU-~{A13} PPU-A7 PPU-A8 PPU-A9 PPU-A11 PPU-A10 PPU-A12 PPU-A13 PPU-D7 PPU-D6 PPU-D5 PPU-D4 CIC-RST CIC-CLK GND
CIC-TO-MB CIC-TO-CART PPU-D3 PPU-D2 PPU-A1 PPU-A2 PPU-A3 PPU-A4 PPU-A5 PPU-A6 VRAM-A10 PPU-~{RD} EXP-4 EXP-3 PPU-D1 PPU-D0 PPU-A0 EXP-2 EXP-1 EXP-0 ~{IRQ}

VCC
~{OE1} 4016-D4 CPU-D4
~{RST} CPU-A0 CPU-A2 CPU-A4

CPU-CLK CPU-D0 CPU-D1 GND

CPU-A10 WRAM-~{CE} VCC

~{ROMSEL} EXP-9 EXP-8 EXP-7 GND

CPU-A8 CPU-A9 CPU-R~{W} CPU-D7 CPU-D6 CPU-D5 CPU-D4 CPU-D3 GND

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

PICTURE PROCESSING UNIT & VIDEO RAM

PPU-A4 PPU-D4 PPU-D0 PPU-D2 PPU-A2 PPU-D6 PPU-A6 GND

EXPANSION CONNECTOR
4016-D4~{OE1} EXP-4 EXP-3 EXP-2 EXP-1 EXP-0 OUT-0 OUT-1 OUT-2 GND

~{RST} PPU-D5 PPU-D6 PPU-D7 PPU-A8 PPU-A9 PPU-D3 PPU-D4 PPU-A10 PPU-A11 PPU-A12VCC

PPU-D0 PPU-D1 PPU-D2 VCC

~{NMI} CPU-A15 EXP-9 EXP-8 EXP-7 EXP-6 EXP-5 ~{OE2} EXP-AUDIO-IN
PPU-A8 PPU-A9ALE

PPU-~{RD} VRAM-A10 VRAM-~{CE} VCC

CPU, PPU, SYSTEM CLOCK CRYSTAL

4016-D2 CPU-D7 PPU-D3 PPU-D4 PPU-D5 PPU-D7 PPU-D6 PPU-~{WE}

PPU-CLK CPU-CLK

Id: 1/1 Title: NES-CPU-11

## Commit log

2019-08-06 Added project file
    [NesRE_Latest.kicad_pcb]
2019-08-12 Create Board_Files\
2019-08-12 Added Component Footprints
2019-08-15 Delete NesRE_Latest.kicad_pcb
    Removed redundant file
    [NesRE_Latest.kicad_pcb]
2019-08-18 Set bottom left corner as 0,0 on grid to simplify measurements
    [Motherboard.kicad_pcb]
2019-09-29 Added .PDF version of Schematic
2019-10-01 Added project files
    [Motherboard.kicad_pcb, Motherboard.sch]
2019-10-02 Assigned footprints to schematic symbols
2019-10-05 git commit -m "Finalized component placement"
    [Motherboard.kicad_pcb, Motherboard.sch]
2019-10-05 Revert "git commit -m "Finalized component placement""
    This reverts commit 3bd8035b65fc1d1872c2f8d4c8690491c7028f2e.
    git revert 3bd8035b65fc1d1872c2f8d4c8690491c7028f2e -m "Reverted redundant commit"
    [Motherboard.kicad_pcb, Motherboard.sch]
2019-10-05 Finalized component placement
    [Motherboard.kicad_pcb, Motherboard.sch]
2019-10-21 Added .PDF and .kicad_pcb files
    [Motherboard.kicad_pcb, Schematic.sch]
2019-12-09 Finalized routing.
    [Motherboard.kicad_pcb, Schematic.sch]
2019-12-09 Added image of board.
2020-01-05 Completed board design
    [Motherboard.kicad_pcb, Schematic.sch]
2020-01-13 Fixed RF Modulator footprint
    [Motherboard.kicad_pcb]
2020-01-14 Uploaded final Gerber files
2020-01-14 Add recommended PCB specs and folder descriptions.
2020-02-13 Removed redundant Gerbers.zip
2020-02-13 Updated RF Modulator footprint
    [Motherboard.kicad_pcb]
2020-03-25 Fixed symbol library issues, and used relative paths for libraries.
    [Motherboard.sch]
2020-05-25 +Added plated layer to edge for RF shield +Improved silkscreen to list unused parts, and fixed overlapping labels +Moved OSHW logo to accommodate the new plated area +Added thermal reliefs to make so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
    [Motherboard.kicad_pcb, Motherboard.sch]
2021-01-08 + Added JST footprint for future open source power/reset button PCB + Fixed outdated RF Modulator footprint + Edited schematic to further improve readability + Added silkscreen denoting PAL and NTSC 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
    [Motherboard.kicad_pcb, Motherboard.sch]
2021-02-15 + Fixed R13 value error
    [Motherboard.kicad_pcb, Motherboard.sch]
2021-06-10 Updated readme photo to show V1.2 PCB, and added note on video output "improvements"
2021-07-24 + Removed expansion audio routing + Removed RST test point + Removed stereo audio solder pads + Removed P6 alt footprint + Removed P6 alt from schematic + Removed R15 from schematic + Re-added missin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
    [Motherboard.kicad_pcb, Motherboard.sch]
2021-11-05 + Added Schematics folder, and schematics for NES-CPU-1/02 and NES-CPU-11 + Fixed pin numbering error in edge connector footprint + Fixed spacing errors in EXP connector footprint + Fixed value error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
    [Motherboard.kicad_pcb, NES-CPU-01_02.sch, NES-CPU-11.sch]
2021-11-05 + Fixed C20 value error + Added sym-lib-table and fp-lib-table to fix symbol/footprint mapping issues
    [Motherboard.sch, NES-CPU-01_02.sch, NES-CPU-11.sch]
2023-01-13 + Added schematics (.sch and .pdf) for NES-CPU-03 and NES-CPU-04
    [NES-CPU-03.sch, NES-CPU-04.sch]
2023-04-02 + Fix C20 silkscreen to reflect the proper value (220pF vs 51pF)
    [Motherboard.kicad_pcb]
2024-07-21 Moved Component Footprints to Libraries folder, migrated to new format, added Dip24 dual width footprint, updated pin 1 of footprints to be square.
2024-07-21 Updated project files to Kicad 8, added local symbol and footprint tables, and .gitignore.
2024-07-21 Updated schematic to Kicad V8, corrected renamed symbols and footprints.
    [Motherboard.kicad_sch]
2024-07-21 Updated pcb to Kicad V8, updated footprints, fixed silkscreen placements, solved drc errors, and tweaked routing.
    [Motherboard.kicad_pcb]
2024-07-21 Added short TO-126-3 footprint with 3d model.
2024-07-21 Updated silkscreen markings, small changes to routing.
    [Motherboard.kicad_pcb, Motherboard.kicad_sch]
2024-08-05 fix: clean up schematic for v8
    [Motherboard.kicad_pcb, Motherboard.kicad_sch]
2024-08-10 fix: fix exp footprint
2024-08-10 chore: update PCB sheet and origins
2024-08-10 chore: update schematic comments
    [Motherboard.kicad_sch]
2024-08-10 feat: add ram footprint with SMD
2024-08-11 feat: implement new ram footprint
    [Motherboard.kicad_sch]
2024-08-11 chore: pcb cleanup
    [Motherboard.kicad_sch]
2024-08-12 Revert "feat: add ram footprint with SMD"
    This reverts commit c8e8e1ad950e63eb5de1c71ab034b8bcab490c6a.
    [Motherboard.kicad_sch]
2024-08-12 fix: updated comments
    [Motherboard.kicad_sch]
2024-08-19 fix: removed custom sheet
    [Motherboard.kicad_sch]
2024-08-20 fix: gerber export settings
2024-08-20 fix: git ignore gerber files
2024-08-20 fix: solder mask
2024-08-20 fix: gerber and drill settings
2024-08-20 fix: edge cut
2024-08-21 fix: footprint updates
2024-08-21 feat: added R15 back
    [Motherboard.kicad_sch]
2024-08-22 feat: added BOM
    [BOM.csv]
2024-08-26 chore: updated printed date
2024-08-29 chore: update README with BOM
2024-08-29 fix: NTSC and PAL BOM
2024-09-26 fix: x1 pads
    [Motherboard.kicad_sch]
2024-09-27 fix: c4 footprint
    [Motherboard.kicad_sch]
2024-09-27 chore: updated BOM
    [BOM.csv]
2024-09-27 chore: BOM clean up
2024-10-14 fix: traces and zones
2024-10-27 feat: added RA2 to BOM
    [BOM.csv]
2024-10-31 fix: exclude from BOM DNP components
    [Motherboard.kicad_sch]
2025-01-04 feat: added interactive bom
2026-01-31 + Migrate files in Schematics/ folder to Kicad 9 + Correct all instances of "CONTROLLER SHIFT REGISTERS" in main schematic and files in Schematics/ folder to "CONTROLLER HEX BUFFERS" + Fix symbol iss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
    [Motherboard.sch, NES-CPU-01_02.kicad_sch, NES-CPU-01_02.sch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]
